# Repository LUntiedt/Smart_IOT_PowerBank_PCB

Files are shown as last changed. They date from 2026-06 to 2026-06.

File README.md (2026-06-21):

# Smart IoT Power Bank — Hardware (PD Edition)

A bidirectional USB-C Power Delivery (PD) power bank built around a software-defined PD stack and an I²C buck-boost charger. This repository holds the **KiCad hardware design** (schematic, layout, BOM, fabrication outputs). The firmware lives in a separate repository.

> **Firmware:** [`smart-iot-power-bank-firmware`](#) 

---

<!-- ───────────────────────────────────────────────────────────── -->
<!-- PROJECT IMAGE — replace the placeholder below with a real photo -->
<!-- Suggested: top-down render or photo of the assembled PCB.       -->
<!-- Drop the file into docs/img/ and update the path.               -->
<!-- ───────────────────────────────────────────────────────────── -->

<p align="center">
  Smart IoT Power Bank PCB
  <br>
  <em>Smart IoT Power Bank</em>
</p>

---

## 1. Overview

The board implements a professional power-management architecture comparable to those found in modern laptops. The same USB-C port handles **input (sink)** and **output (source/OTG)**, limited to a robust **30 W**. Energetic characterization (V/I telemetry, efficiency) is done entirely with the **internal 16-bit ADCs of the charge controller**, avoiding external sense amplifiers.

| Property | Value |
| :--- | :--- |
| Topology | Bidirectional USB-C PD (sink + source) |
| Battery | 4S1P Li-ion, 14.8 V nominal (~45 Wh) with integrated protection BMS |
| Max power | 30 W (5 V / 9 V / 12 V / 15 V / 20 V profiles) |
| MCU | ESP32-C3 (Wi-Fi/BLE) |
| Charger | TI BQ25792 I²C buck-boost |
| PD PHY | onsemi FUSB302B |
| Logic rail | TPS54202 buck → 3.3 V |
| EDA tool | KiCad |
| Fab house | [Aisler](https://aisler.net) (stackup & design rules tuned to Aisler) |

---

## 2. Hardware Architecture

### A. Power Path & USB-C Communication

| Designator | Part | Function | System Role |
| :--- | :--- | :--- | :--- |
| **U3** | `BQ25792RQMR` (TI) | I²C buck-boost charger | Handles charging (buck) and discharging (OTG/boost) in hardware. Single inductor L1 (2.2 µH). |
| **U1** | `FUSB302B11MPX` (onsemi) | USB Type-C PD PHY | Monitors the CC pins and translates PD signalling into I²C messages for the MCU. |
| **U6** | `TPS54202HDDCR` (TI) | 2 A step-down | Generates a clean **3.3 V** logic rail from the fluctuating system voltage. Inductor L2 (10 µH). |
| **Q1, Q2** | `CSD17581Q3A` (TI) | Dual N-channel MOSFETs | Back-to-back FETs for **reverse-polarity protection** / VBUS load isolation; block reverse current from the USB port into the system. |
| **J2** | Würth WR-MPC4 `64900311122` | Battery connector | Connects the external **4S1P 18650 pack** (14.8 V, ~45 Wh, with internal BMS). |

### B. Protection (TVS / ESD / Clamps)

| Designator | Part | Function | Notes |
| :--- | :--- | :--- | :--- |
| **U2, U4** | `TVS2200DRVR` (TI) | Flat-clamp surge protection | **VBUS TVS** — tight clamping on the high-current bus. |
| **D2, D4** | `TPD4E05U06DQAR` (TI) | 4-channel low-cap ESD | Protects **CC lines and the differential pairs** without loading the high-speed signals. |
| **D1** | `ZLLS350` (Diodes Inc.) | 40 V Schottky | Power-path / bootstrap diode. |
| **Z1** | `MMSZ5242B` | 12 V Zener | Rail clamp. |

### C. Sensing & Intelligence (IoT layer)

| Designator | Part | Function | Engineering benefit |
| :--- | :--- | :--- | :--- |
| **U5** | `ESP32-C3-WROOM-02-H4` (Espressif) | Master MCU | FSM control, software PD stack, I²C master, BLE server. |
| — | BQ25792 (internal) | 16-bit ADC telemetry | Reads V_BUS, I_BUS, V_BAT, I_BAT from the charger — no external current sensors. |
| **(TS pin)** | 10 k NTC | Thermistor | Cell temperature monitoring via the BQ25792 TS pin. |
| **J5** | 1×04 header | OLED / I²C | 0.96" OLED for local PD-profile and efficiency readout. |

### D. Connectors, Switches, Indicators

| Designator | Part | Function |
| :--- | :--- | :--- |
| **J1, J3** | USB-C receptacle (Würth `629722000214`) | Two USB-C ports — see differential-pair routing below. |
| **J4** | 2×03 header | Programming / debug header. |
| **SW1, SW2** | Würth tactile `434121025816` | Boot / reset buttons. |
| **D3** | Green LED (Würth) | Status indication. |

> Full part list with manufacturer numbers, footprints and datasheets: **[`ESP_Smart_IoT_Power_Bank.csv`](ESP_Smart_IoT_Power_Bank.csv)**.

---

## 3. Engineering Features & Physics

### I. Cascaded Power Supply (Logic Isolation)

To avoid system reboots under heavy load, the supply is cascaded:

1. **Primary stage** — the BQ25792 generates the system rail `V_SYS` from the 4S pack.
2. **Secondary stage** — a dedicated **TPS54202** bucks `V_SYS` down to a constant **3.3 V** for the logic. The ESP32 therefore always sees a clean rail, independent of current spikes in the power stage.

### II. Efficient 4S Power Routing (Buck & OTG)

The 4S pack (14.8 V) minimizes conversion losses:

* **Buck mode (sink):** at 20 V input the IC acts as an efficient step-down.
* **Buck/boost mode (source):** in OTG, 5 V / 9 V / 12 V are produced highly efficiently by buck conversion; only 20 V profiles (e.g. laptops) require a slight boost.

### III. Thermal & Electrical Derating

Thanks to the 4S configuration, PCB currents stay **below 3 A** even at 30 W:

```
I_bat_max = P_out / (U_bat · η)
I_bat_max = 30 W / (12.0 V · 0.9) ≈ 2.7 A   (worst case, empty pack)
```

On overheat (NTC > 60 °C) the ESP32 throttles PD power via software re-negotiation down to **5 W (5 V / 1 A)** as a fallback.

---

## 4. PCB Stackup & Layout

**4-layer board, built to Aisler's stackup and design rules.**

| Layer | Role |
| :--- | :--- |
| **Top** | Power / Signal |
| **Inner 1** | GND |
| **Inner 2** | GND |
| **Bottom** | Power / Signal |

The dual inner ground planes give the high-speed pairs a continuous reference and a low-impedance return for the power stage.

### Differential pairs

Two **impedance-controlled 90 Ω differential pairs** (USB 2.0 spec):

1. **USB power port (BQ25792):** backwards-compatible USB data for the power path.
2. **Debug/flash port (ESP32-C3):** USB used to flash and debug the MCU.

Both pairs are protected by the low-capacitance `TPD4E05U06` ESD arrays so the added capacitance does not degrade signal integrity.

### Layout guidelines

* **Ground partitioning** — clean ground concept separating the power stage (BQ25792) from the logic (ESP32 / TPS54202).
* **Copper polygons** — power paths (V_BUS, V_BAT, V_SYS) routed as filled polygons.
* **Thermal management** — implemented high power rails on both sides of the board to increase thermal capacity and placing a generous amount of vias to distribute current evenly

---

## 5. Design Decisions Log

* **Dual-MOSFET reverse-polarity protection** (Q1/Q2, CSD17581Q3A) instead of a single series diode — near-zero conduction loss on the power path.
* **VBUS TVS** (TVS2200) for surge clamping on the high-current bus.
* **Low-capacitance TVS/ESD** (TPD4E05U06) on CC lines and the differential pairs to preserve signal integrity.
* **Two 90 Ω impedance-controlled diff pairs:** one for backwards-compatible USB power data (BQ), one dedicated to flashing/debugging the MCU.
* **Aisler** chosen as fab house — the stackup and design rules in this project are tuned to Aisler's process.

---

## 6. Status

Hardware design in KiCad. See the firmware repository for the FreeRTOS PD stack.

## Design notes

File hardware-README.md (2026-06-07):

# Smart IoT Power Bank — Hardware (PD Edition)

A bidirectional USB-C Power Delivery (PD) power bank built around a software-defined PD stack and an I²C buck-boost charger. This repository holds the **KiCad hardware design** (schematic, layout, BOM, fabrication outputs). The firmware lives in a separate repository.

> **Firmware:** [`smart-iot-power-bank-firmware`](#) *(replace with link)*

---

<!-- ───────────────────────────────────────────────────────────── -->
<!-- PROJECT IMAGE — replace the placeholder below with a real photo -->
<!-- Suggested: top-down render or photo of the assembled PCB.       -->
<!-- Drop the file into docs/img/ and update the path.               -->
<!-- ───────────────────────────────────────────────────────────── -->

<p align="center">
  Smart IoT Power Bank PCB
  <br>
  <em>📷 Placeholder — add a photo/render of the power bank here.</em>
</p>

---

## 1. Overview

The board implements a professional power-management architecture comparable to those found in modern laptops. The same USB-C port handles **input (sink)** and **output (source/OTG)**, limited to a robust **30 W**. Energetic characterization (V/I telemetry, efficiency) is done entirely with the **internal 16-bit ADCs of the charge controller**, avoiding external sense amplifiers.

| Property | Value |
| :--- | :--- |
| Topology | Bidirectional USB-C PD (sink + source) |
| Battery | 4S1P Li-ion, 14.8 V nominal (~45 Wh) with integrated protection BMS |
| Max power | 30 W (5 V / 9 V / 12 V / 15 V / 20 V profiles) |
| MCU | ESP32-C3 (Wi-Fi/BLE) |
| Charger | TI BQ25792 I²C buck-boost |
| PD PHY | onsemi FUSB302B |
| Logic rail | TPS54202 buck → 3.3 V |
| EDA tool | KiCad |
| Fab house | [Aisler](https://aisler.net) (stackup & design rules tuned to Aisler) |

---

## 2. Hardware Architecture

### A. Power Path & USB-C Communication

| Designator | Part | Function | System Role |
| :--- | :--- | :--- | :--- |
| **U3** | `BQ25792RQMR` (TI) | I²C buck-boost charger | Handles charging (buck) and discharging (OTG/boost) in hardware. Single inductor L2 (10 µH). |
| **U1** | `FUSB302B11MPX` (onsemi) | USB Type-C PD PHY | Monitors the CC pins and translates PD signalling into I²C messages for the MCU. |
| **U6** | `TPS54202HDDCR` (TI) | 2 A step-down | Generates a clean **3.3 V** logic rail from the fluctuating system voltage. Inductor L1 (2.2 µH). |
| **Q1, Q2** | `CSD17581Q3A` (TI) | Dual N-channel MOSFETs | Back-to-back FETs for **reverse-polarity protection** / VBUS load isolation; block reverse current from the USB port into the system. |
| **J2** | Würth WR-MPC4 `64900311122` | Battery connector | Connects the external **4S1P 18650 pack** (14.8 V, ~45 Wh, with internal BMS). |

### B. Protection (TVS / ESD / Clamps)

| Designator | Part | Function | Notes |
| :--- | :--- | :--- | :--- |
| **U2, U4** | `TVS2200DRVR` (TI) | Flat-clamp surge protection | **VBUS TVS** — tight clamping on the high-current bus. |
| **D2, D4** | `TPD4E05U06DQAR` (TI) | 4-channel low-cap ESD | Protects **CC lines and the differential pairs** without loading the high-speed signals. |
| **D1** | `ZLLS350` (Diodes Inc.) | 40 V Schottky | Power-path / bootstrap diode. |
| **Z1** | `MMSZ5242B` | 12 V Zener | Rail clamp. |

### C. Sensing & Intelligence (IoT layer)

| Designator | Part | Function | Engineering benefit |
| :--- | :--- | :--- | :--- |
| **U5** | `ESP32-C3-WROOM-02-H4` (Espressif) | Master MCU | FSM control, software PD stack, I²C master, BLE server. |
| — | BQ25792 (internal) | 16-bit ADC telemetry | Reads V_BUS, I_BUS, V_BAT, I_BAT from the charger — no external current sensors. |
| **(TS pin)** | 10 k NTC | Thermistor | Cell temperature monitoring via the BQ25792 TS pin. |
| **J5** | 1×04 header | OLED / I²C | 0.96" OLED for local PD-profile and efficiency readout. |

### D. Connectors, Switches, Indicators

| Designator | Part | Function |
| :--- | :--- | :--- |
| **J1, J3** | USB-C receptacle (Würth `629722000214`) | Two USB-C ports — see differential-pair routing below. |
| **J4** | 2×03 header | Programming / debug header. |
| **SW1, SW2** | Würth tactile `434121025816` | Boot / reset buttons. |
| **D3** | Green LED (Würth) | Status indication. |

> Full part list with manufacturer numbers, footprints and datasheets: **[`ESP_Smart_IoT_Power_Bank.csv`](ESP_Smart_IoT_Power_Bank.csv)**.

---

## 3. Engineering Features & Physics

### I. Cascaded Power Supply (Logic Isolation)

To avoid system reboots under heavy load, the supply is cascaded:

1. **Primary stage** — the BQ25792 generates the system rail `V_SYS` from the 4S pack.
2. **Secondary stage** — a dedicated **TPS54202** bucks `V_SYS` down to a constant **3.3 V** for the logic. The ESP32 therefore always sees a clean rail, independent of current spikes in the power stage.

### II. Efficient 4S Power Routing (Buck & OTG)

The 4S pack (14.8 V) minimizes conversion losses:

* **Buck mode (sink):** at 20 V input the IC acts as an efficient step-down.
* **Buck/boost mode (source):** in OTG, 5 V / 9 V / 12 V are produced highly efficiently by buck conversion; only 20 V profiles (e.g. laptops) require a slight boost.

### III. Thermal & Electrical Derating

Thanks to the 4S configuration, PCB currents stay **below 3 A** even at 30 W:

```
I_bat_max = P_out / (U_bat · η)
I_bat_max = 30 W / (12.0 V · 0.9) ≈ 2.7 A   (worst case, empty pack)
```

On overheat (NTC > 60 °C) the ESP32 throttles PD power via software re-negotiation down to **5 W (5 V / 1 A)** as a fallback.

---

## 4. PCB Stackup & Layout

**4-layer board, built to Aisler's stackup and design rules.**

| Layer | Role |
| :--- | :--- |
| **Top** | Signal |
| **Inner 1** | GND |
| **Inner 2** | GND |
| **Bottom** | Power / Signal |

The dual inner ground planes give the high-speed pairs a continuous reference and a low-impedance return for the power stage.

### Differential pairs

Two **impedance-controlled 90 Ω differential pairs** (USB 2.0 spec):

1. **USB power port (BQ25792):** backwards-compatible USB data for the power path.
2. **Debug/flash port (ESP32-C3):** USB used to flash and debug the MCU.

Both pairs are protected by the low-capacitance `TPD4E05U06` ESD arrays so the added capacitance does not degrade signal integrity.

### Layout guidelines

* **Ground partitioning** — clean ground concept separating the power stage (BQ25792) from the logic (ESP32 / TPS54202).
* **Copper polygons** — power paths (V_BUS, V_BAT, V_SYS) routed as filled polygons.
* **Thermal management** — the BQ25792 thermal pad uses a dense GND-via array to conduct heat into the inner copper layers.

---

## 5. Design Decisions Log

* **Dual-MOSFET reverse-polarity protection** (Q1/Q2, CSD17581Q3A) instead of a single series diode — near-zero conduction loss on the power path.
* **VBUS TVS** (TVS2200) for surge clamping on the high-current bus.
* **Low-capacitance TVS/ESD** (TPD4E05U06) on CC lines and the differential pairs to preserve signal integrity.
* **Two 90 Ω impedance-controlled diff pairs:** one for backwards-compatible USB power data (BQ), one dedicated to flashing/debugging the MCU.
* **Aisler** chosen as fab house — the stackup and design rules in this project are tuned to Aisler's process.

---

## 6. Repository Structure

```
.
├── docs/
│   └── img/                 # photos / renders (add powerbank.png here)
├── *.kicad_pro              # KiCad project
├── *.kicad_sch              # schematic
├── *.kicad_pcb              # board layout
├── ESP_Smart_IoT_Power_Bank.csv   # bill of materials
└── README.md
```

## 7. Status

Hardware design in KiCad. See the firmware repository for the FreeRTOS PD stack.

## 8. License

*Add a license (e.g. CERN-OHL-S for hardware) before publishing.*

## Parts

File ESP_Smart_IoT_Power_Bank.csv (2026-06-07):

Reference | Qty | Value | DNP | Exclude from BOM | Exclude from Board | Footprint | Datasheet | Manufacturer_Part_Number
C1,C35 | 2 | 1n |  |  |  | 00_PowerBank_FTP:C_Wurth_WCAP-CSGP-0402 | https://www.we-online.com/catalog/datasheet/885012205061.pdf?ki | 885012205061
C2,C3,C6,C38,C40 | 5 | 1u |  |  |  | 00_PowerBank_FTP:C_Wurth_WCAP-CSGP-1206_H1.6 | https://www.we-online.com/catalog/datasheet/885012208093.pdf?ki | 885012208093
C4 | 1 | 10n |  |  |  | 00_PowerBank_FTP:C_Wurth_WCAP-CSGP-0402 | https://www.we-online.com/catalog/datasheet/885012205067.pdf?ki | 885012205067
C5,C7,C17,C18,C20,C30,C33,C37,C41,C44 | 10 | 100n |  |  |  | 00_PowerBank_FTP:C_Wurth_WCAP-CSGP-0402 | https://www.we-online.com/catalog/datasheet/885012205086.pdf?ki | 885012205086
C8,C13,C14,C15,C16,C21,C22,C23,C24,C25,C27,C28,C29,C31,C32,C36,C42,C43 | 18 | 10u |  |  |  | 00_PowerBank_FTP:C_Wurth_WCAP-CSGP-1206_H1.6 | https://www.we-online.com/catalog/datasheet/885012208069.pdf?ki | 885012208069
C9,C10 | 2 | 330p |  |  |  | 00_PowerBank_FTP:C_Wurth_WCAP-CSGP-0402 | https://www.we-online.com/catalog/datasheet/885012005016.pdf?ki | 885012005016
C11,C39 | 2 | 4n7 |  |  |  | 00_PowerBank_FTP:C_Wurth_WCAP-CSGP-0402 | https://www.we-online.com/catalog/datasheet/885012205065.pdf?ki | 885012205065
C12,C19 | 2 | 47n |  |  |  | 00_PowerBank_FTP:C_Wurth_WCAP-CSGP-0402 | https://www.we-online.com/catalog/datasheet/885012205054.pdf?ki | 885012205054
C26 | 1 | 4u7 |  |  |  | 00_PowerBank_FTP:C_Wurth_WCAP-CSGP-1206_H1.6 | https://www.we-online.com/catalog/datasheet/885012208068.pdf?ki | 885012208068
C34 | 1 | 47n |  |  |  | 00_PowerBank_FTP:C_Wurth_WCAP-CSGP-0603_R | https://www.we-online.com/catalog/datasheet/885012206093.pdf?ki | 885012206093
C45,C46 | 2 | 22u |  |  |  | 00_PowerBank_FTP:C_Wurth_WCAP-CSGP-1206_H1.6 | https://www.we-online.com/catalog/datasheet/885012108018.pdf?ki | 885012108018
C47 | 1 | 56p |  |  |  | 00_PowerBank_FTP:C_Wurth_WCAP-CSGP-0402 | http://www.vishay.com/docs/45226/vj31xrohsautomlcc.pdf | VJ0402A560JXAAC
D1 | 1 | 40V |  |  |  | 00_PowerBank_FTP:SODFL1608X65N | https://www.diodes.com//assets/Datasheets/ZLLS350.pdf | ZLLS350TA
D2,D4 | 2 | TPD4E05U06DQAR |  |  |  | 00_PowerBank_FTP:DQA_R-PUSON-N10_ | http://www.ti.com/lit/gpn/tpd4e05u06 | TPD4E05U06DQAR
D3 | 1 | Green |  |  |  | 00_PowerBank_FTP:D_Wurth_WL-SMCW-0603 | https://www.we-online.com/catalog/datasheet/150060VS75000.pdf?ki | 150060VS75000
J1,J3 | 2 | USB_C_Receptacle_USB2.0_16P_Wuerth_Lorenzo |  |  |  | 00_PowerBank_FTP:629722000214 | https://www.usb.org/sites/default/files/documents/usb_type-c.zip | 629722000214
J2 | 1 | 64900311122 |  |  |  | 00_PowerBank_FTP:J_Wurth_WR-MPC4_64900311122 | https://www.we-online.com/en/components/products/datasheet/64900311122?ki | 64900311122
J4 | 1 | Conn_02x03_Odd_Even |  |  |  | Connector_PinHeader_2.54mm:PinHeader_2x03_P2.54mm_Vertical
J5 | 1 | Conn_01x04_Pin |  |  |  | Connector_PinHeader_2.54mm:PinHeader_1x04_P2.54mm_Vertical
L1 | 1 | 2.2 uH |  |  |  | 00_PowerBank_FTP:L_Wurth_WE-LHMI-7030 | https://www.we-online.com/catalog/datasheet/74437346022.pdf?ki | 74437346022
L2 | 1 | 10.0 uH |  |  |  | 00_PowerBank_FTP:L_Wurth_WE-LHMI-7050 | https://www.we-online.com/catalog/datasheet/74437349100.pdf?ki | 74437349100
Q1,Q2 | 2 | CSD17581Q3A |  |  |  | 00_PowerBank_FTP:CSD17581Q3A_LorenzonF | https://www.ti.com/lit/ds/symlink/csd17581q3a.pdf | CSD17581Q3A
R1 | 1 | 2 |  |  |  | 00_PowerBank_FTP:R_Wurth_WRIS-RSKS-0402 | https://www.we-online.com/catalog/datasheet/560112110057.pdf?ki | 560112110057
R2 | 1 | 301 |  |  |  | 00_PowerBank_FTP:R_Wurth_WRIS-RSKS-0402 | https://www.we-online.com/catalog/datasheet/560112110092.pdf?ki | 560112110092
R3,R16 | 2 | 1M |  |  |  | 00_PowerBank_FTP:R_Wurth_WRIS-RSKS-0402 | https://www.we-online.com/catalog/datasheet/560112110033.pdf?ki | 560112110033
R4 | 1 | 2k2 |  |  |  | 00_PowerBank_FTP:R_Wurth_WRIS-RSKS-0402 | https://www.we-online.com/catalog/datasheet/560112110087.pdf?ki | 560112110087
R5 | 1 | 100 |  |  |  | 00_PowerBank_FTP:R_Wurth_WRIS-RSKS-0402 | https://www.we-online.com/catalog/datasheet/560112110022.pdf?ki | 560112110022
R6 | 1 | 127k |  |  |  | 00_PowerBank_FTP:R_Wurth_WRIS-RSKS-0402 | https://www.we-online.com/catalog/datasheet/560112110195.pdf?ki | 560112110195
R7 | 1 | 27k |  |  |  | 00_PowerBank_FTP:R_Wurth_WRIS-RSKS-0402 | https://www.we-online.com/catalog/datasheet/560112110026.pdf?ki | 560112110026
R8,R26 | 2 | 100k |  |  |  | 00_PowerBank_FTP:R_Wurth_WRIS-RSKS-0402 | https://www.we-online.com/catalog/datasheet/560112110019.pdf?ki | 560112110019
R9 | 1 | 5k23 |  |  |  | 00_PowerBank_FTP:R_Wurth_WRIS-RSKS-0402 | https://industrial.panasonic.com/cdbs/www-data/pdf/RDP0000/AOA0000C334.pdf | ERJ-U02D5231X
R10 | 1 | 30k1 |  |  |  | 00_PowerBank_FTP:R_Wurth_WRIS-RSKS-0402 |  | ERJ-2RHD3012X
R11,R12 | 2 | 4k7 |  |  |  | 00_PowerBank_FTP:R_Wurth_WRIS-RSKS-0402 | https://www.we-online.com/catalog/datasheet/560112110245.pdf?ki | 560112110245
R13,R18 | 2 | 1k |  |  |  | 00_PowerBank_FTP:R_Wurth_WRIS-RSKS-0402 | https://www.we-online.com/catalog/datasheet/560112110012.pdf?ki | 560112110012
R14,R15,R17,R19,R23,R25 | 6 | 10k |  |  |  | 00_PowerBank_FTP:R_Wurth_WRIS-RSKS-0402 | https://www.we-online.com/catalog/datasheet/560112110020.pdf?ki | 560112110020
R20,R21 | 2 | 5k1 |  |  |  | 00_PowerBank_FTP:R_Wurth_WRIS-RSKS-0402 | http://docs-europe.electrocomponents.com/webdocs/13ba/0900766b813ba21b.pdf | ERJ2RKF5101X
R22 | 1 | 510k |  |  |  | 00_PowerBank_FTP:R_Wurth_WRIS-RSKS-0402 | https://industrial.panasonic.com/cdbs/www-data/pdf/RDP0000/AOA0000C334.pdf | ERJ-U02F5103X
R24 | 1 | 49.9 |  |  |  | 00_PowerBank_FTP:R_Wurth_WRIS-RSKS-0402 | https://www.we-online.com/catalog/datasheet/560112110002.pdf?ki | 560112110002
R27 | 1 | 22k1 |  |  |  | 00_PowerBank_FTP:R_Wurth_WRIS-RSKS-0402 | https://www.we-online.com/catalog/datasheet/560112110099.pdf?ki | 560112110099
SW1,SW2 | 2 | 434121025816 |  |  |  | 00_PowerBank_FTP:SW_Wurth_WS-TASV_434121025816 | https://www.we-online.com/catalog/datasheet/434121025816.pdf?ki | 434121025816
U1 | 1 | FUSB302B11MPX |  |  |  | 00_PowerBank_FTP:QFN50P250X250X80-15N | https://www.onsemi.com/pub/Collateral/FUSB302B-D.PDF | FUSB302B11MPX
U2,U4 | 2 | TVS2200DRVR |  |  |  | 00_PowerBank_FTP:SON65P200X200X80-7N | https://www.ti.com/lit/ds/symlink/tvs2200.pdf?ts=1636348695619 | TVS2200DRVR
U3 | 1 | BQ25792RQMR |  |  |  | 00_PowerBank_FTP:BQ25792RQMR |  | BQ25792RQMR
U5 | 1 | ESP32-C3-WROOM-02-H4 |  |  |  | 00_PowerBank_FTP:ESP32C3WROOM02H4 | https://www.mouser.in/datasheet/2/891/Espressif_Systems_04082021_ESP32_C3_WROOM_02-2295851.pdf | ESP32-C3-WROOM-02-H4
U6 | 1 | TPS54202HDDCR |  |  |  | 00_PowerBank_FTP:SOT95P280X110-6N | http://www.ti.com/lit/gpn/tps54202h | TPS54202HDDCR
Z1 | 1 | 12V |  |  |  | 00_PowerBank_FTP:SOD3716X145N | https://www.diodes.com//assets/Datasheets/ds18010.pdf | MMSZ5242B-7-F

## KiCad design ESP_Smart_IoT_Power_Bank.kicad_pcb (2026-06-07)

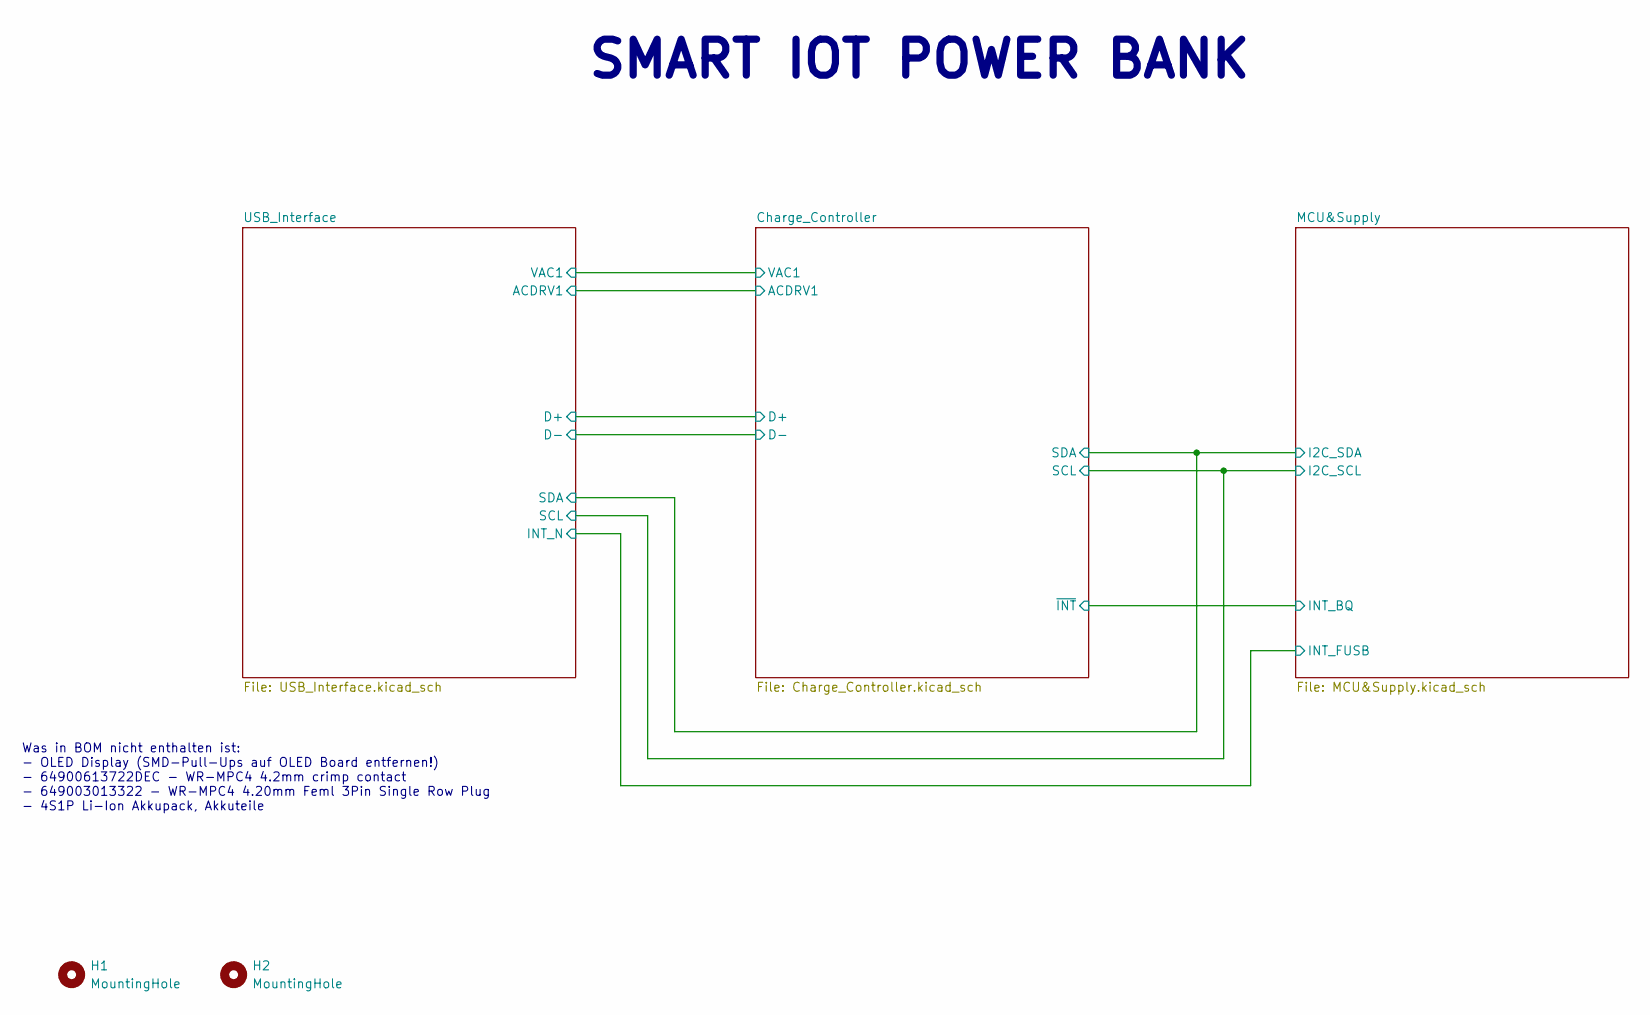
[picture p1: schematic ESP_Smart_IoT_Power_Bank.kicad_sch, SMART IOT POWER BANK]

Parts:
H1, H2: MountingHole; MountingHole_3.2mm_M3_ISO14580

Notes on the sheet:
SMART IOT POWER BANK
Was in BOM nicht enthalten ist: - OLED Display (SMD-Pull-Ups auf OLED Board entfernen!) - 64900613722DEC - WR-MPC4 4.2mm crimp contact - 649003013322 - WR-MPC4 4.20mm Feml 3Pin Single Row Plug - 4S1P Li-Ion Akkupack, Akkuteile

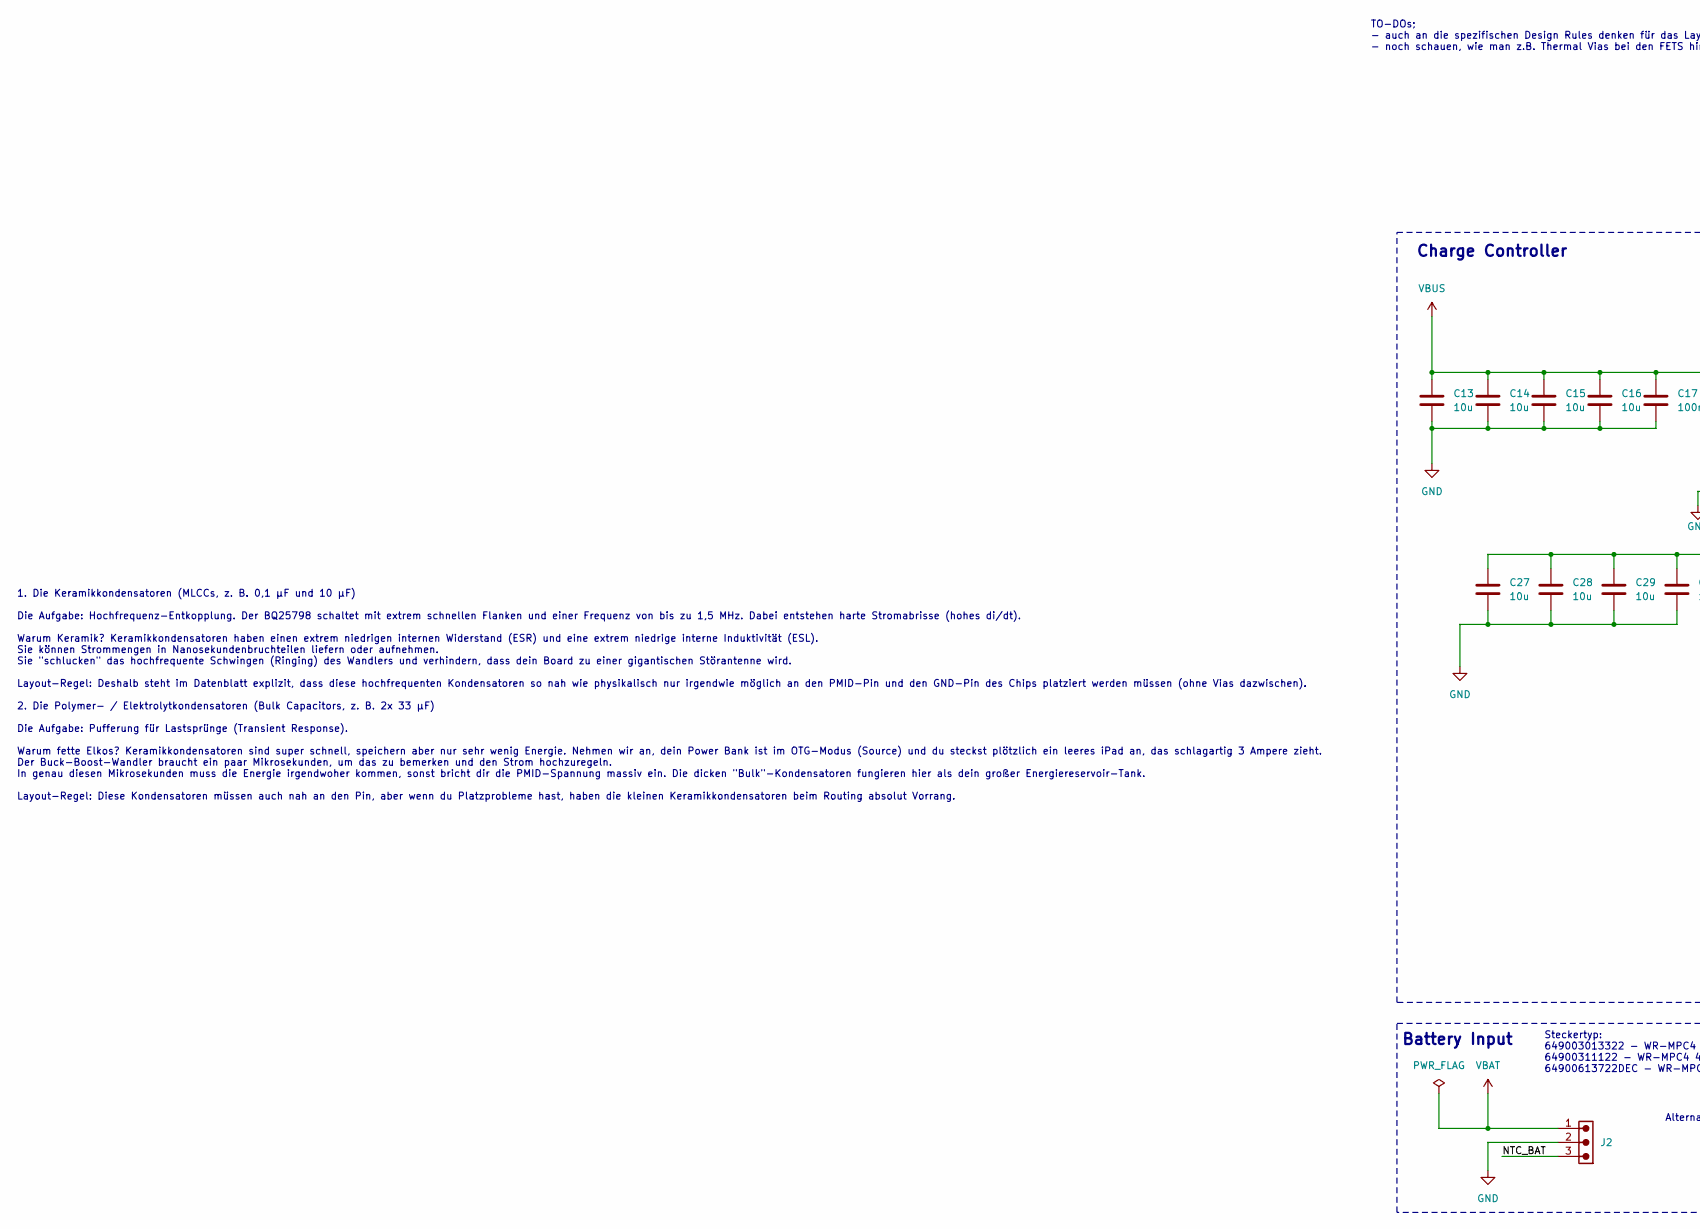
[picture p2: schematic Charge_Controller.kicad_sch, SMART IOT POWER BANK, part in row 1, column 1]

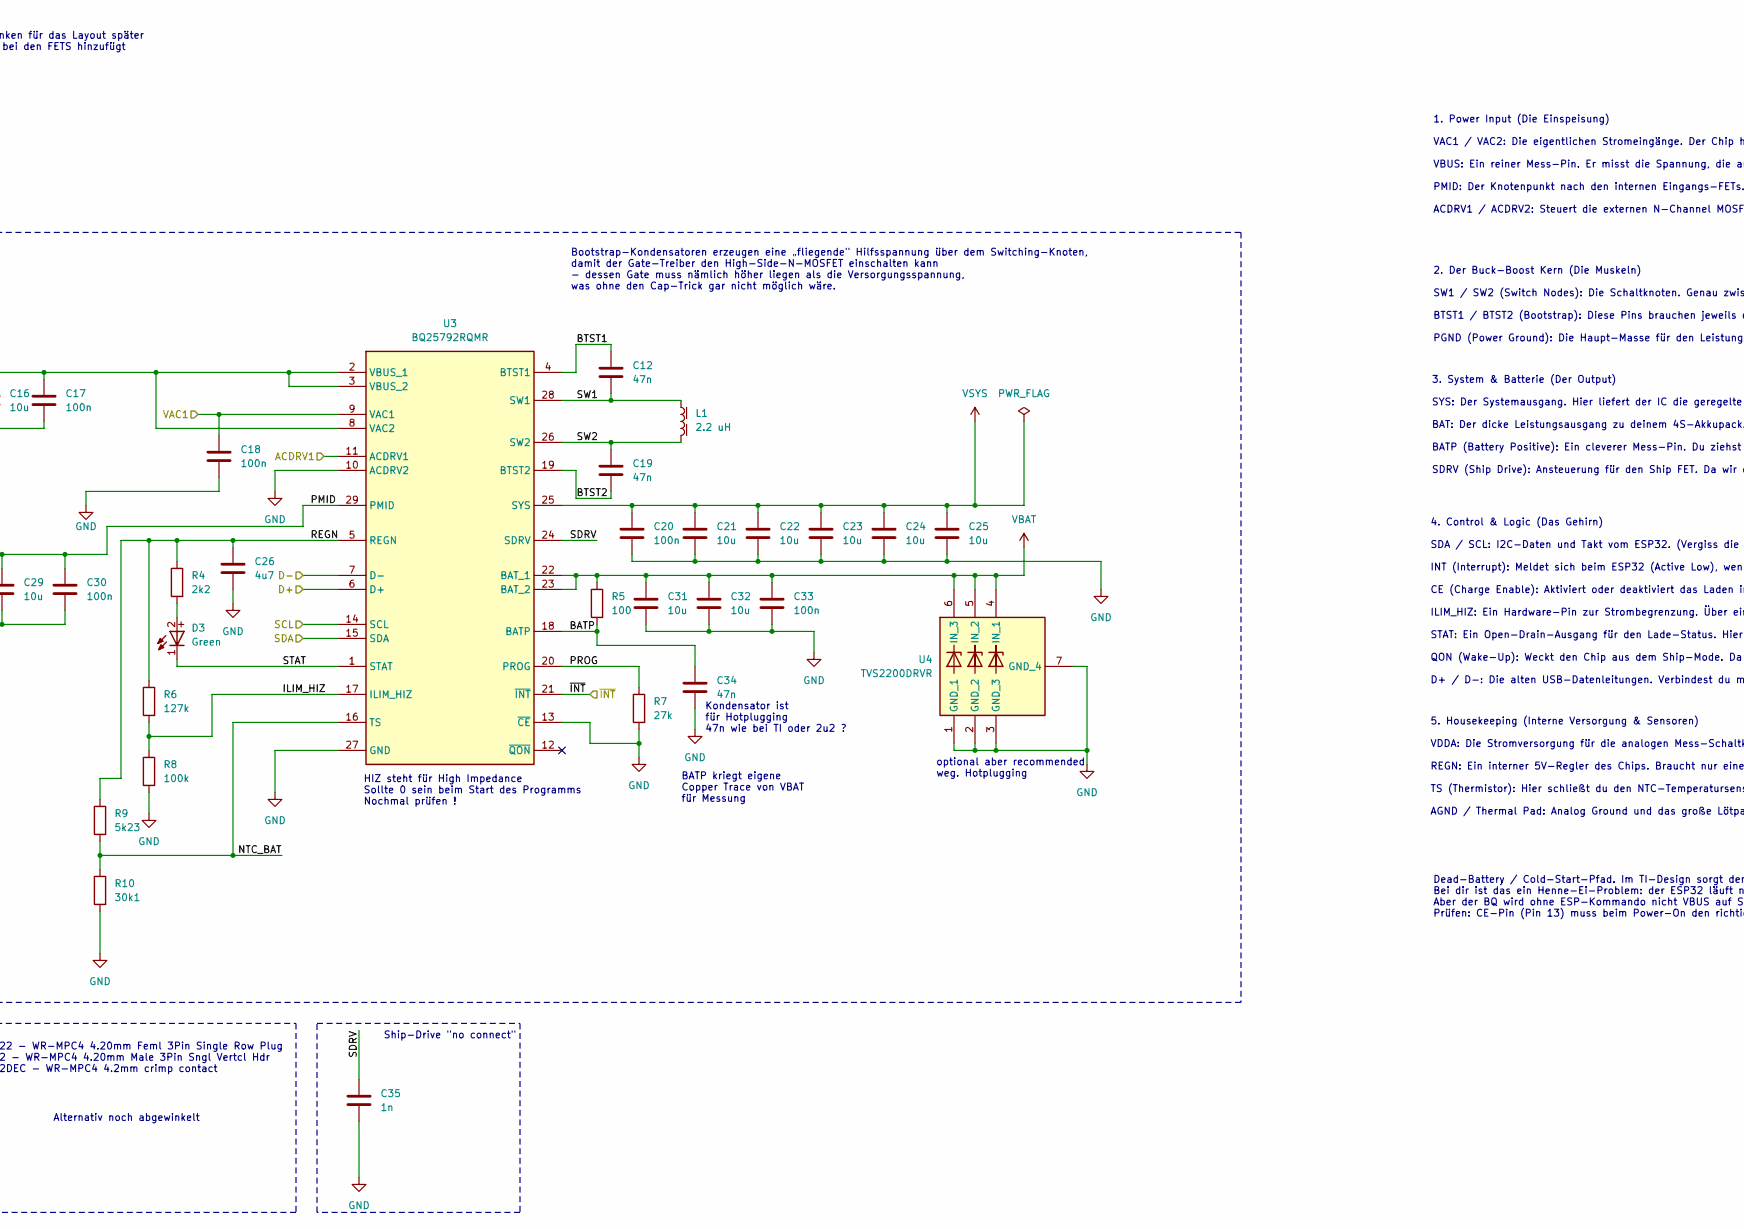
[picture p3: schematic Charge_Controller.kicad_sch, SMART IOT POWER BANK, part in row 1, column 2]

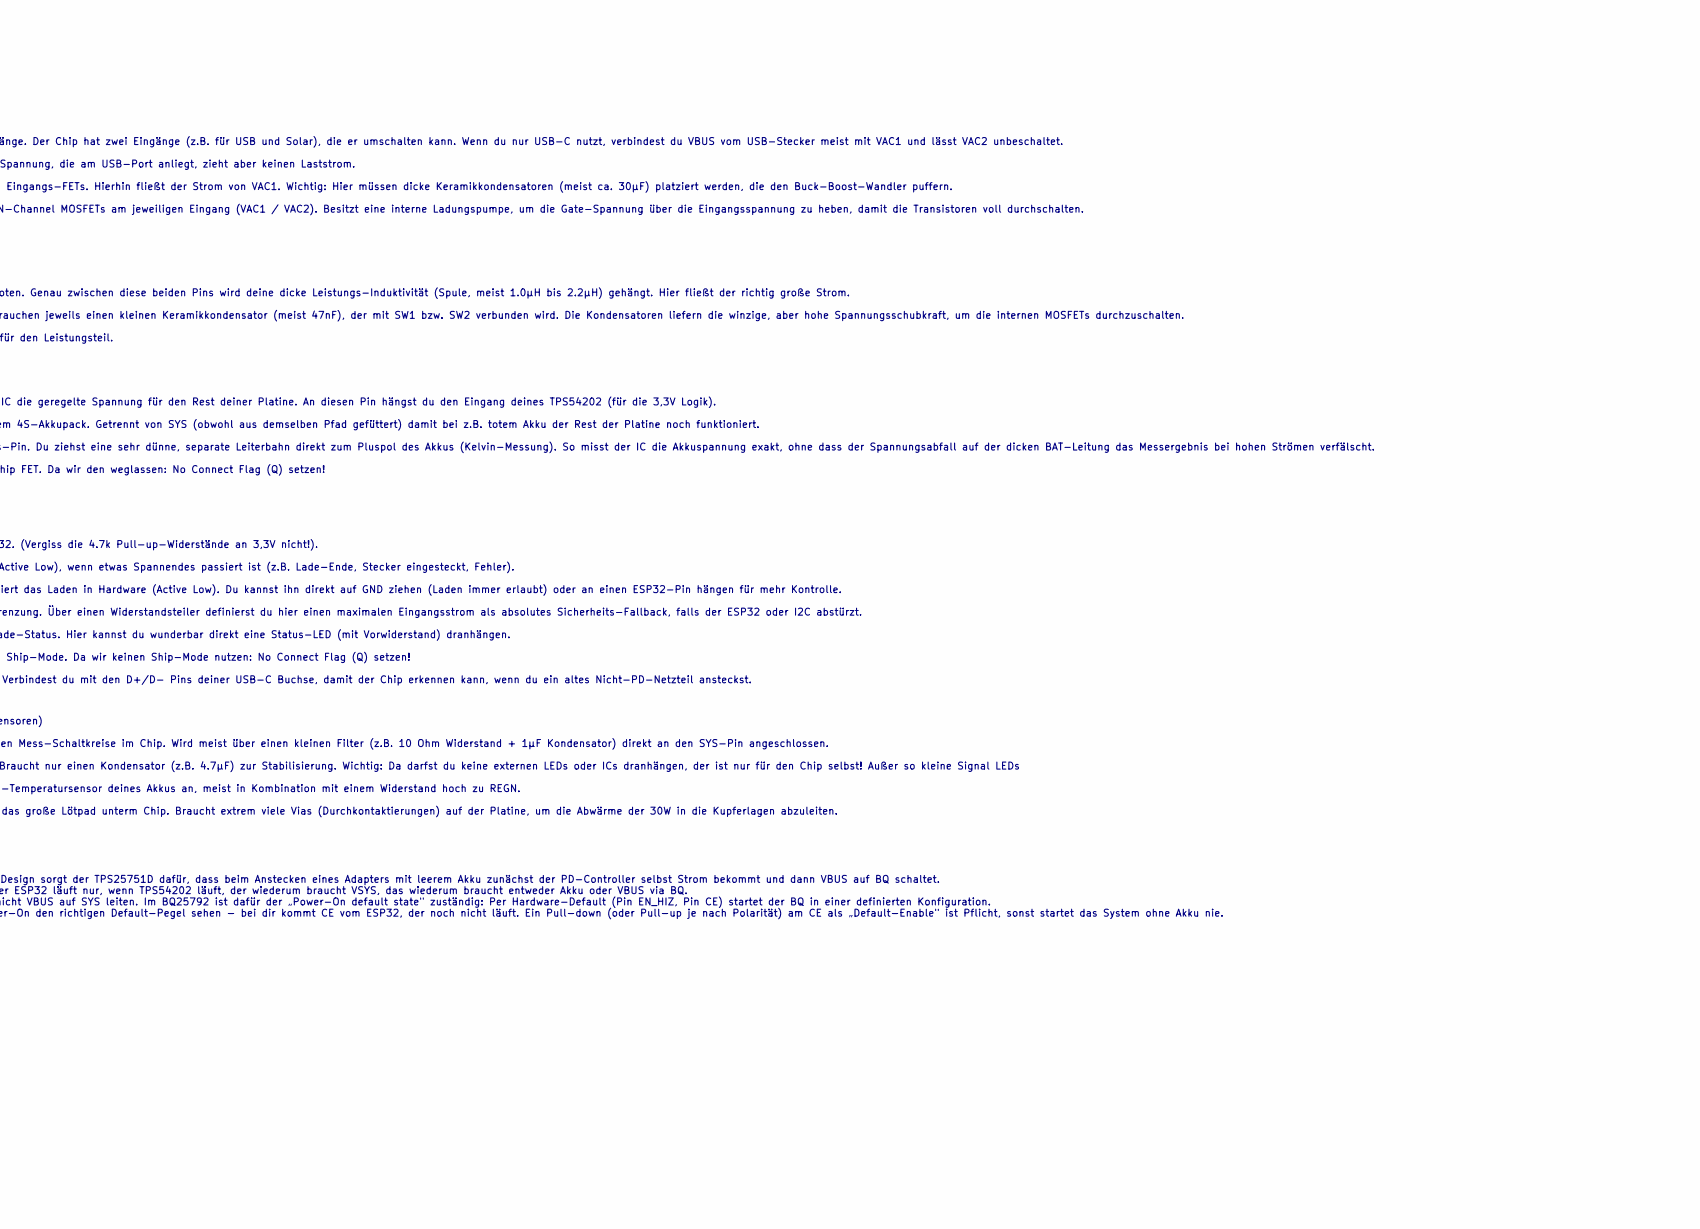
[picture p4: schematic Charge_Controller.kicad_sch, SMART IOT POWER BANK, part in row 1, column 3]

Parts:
C12, C19: 47n; C_Wurth_WCAP-CSGP-0402; Voltage 25.0; Manufacturer_Part_Number 885012205054
C13, C14, C15, C16, C21, C22, C23, C24, C25, C27, C28, C29, C31, C32: 10u; C_Wurth_WCAP-CSGP-1206_H1.6; Voltage 25.0; Part Number 885012208069
C17, C18, C20, C30, C33: 100n; C_Wurth_WCAP-CSGP-0402; Voltage 50.0; Part Number 885012205086
C26: 4u7; C_Wurth_WCAP-CSGP-1206_H1.6; Voltage 25.0; Part Number 885012208068
C34: 47n; C_Wurth_WCAP-CSGP-0603_R; Voltage 50.0; Part Number 885012206093
C35: 1n; C_Wurth_WCAP-CSGP-0402; Voltage 50.0; Part Number 885012205061
D3: Green; D_Wurth_WL-SMCW-0603; Part Number 150060VS75000
J2: 64900311122; J_Wurth_WR-MPC4_64900311122; Working Voltage (V (AC)) 600; Manufacturer_Part_Number 64900311122
L1: 2.2 uH; L_Wurth_WE-LHMI-7030; Part Number 74437346022
R4: 2k2; R_Wurth_WRIS-RSKS-0402; Part Number 560112110087
R5: 100; R_Wurth_WRIS-RSKS-0402; Part Number 560112110022
R6: 127k; R_Wurth_WRIS-RSKS-0402; Part Number 560112110195
R7: 27k; R_Wurth_WRIS-RSKS-0402; Part Number 560112110026
R8: 100k; R_Wurth_WRIS-RSKS-0402; Part Number 560112110019
R9: 5k23; R_Wurth_WRIS-RSKS-0402; Manufacturer_Part_Number ERJ-U02D5231X
R10: 30k1; R_Wurth_WRIS-RSKS-0402; Mouser Part Number 667-ERJ-2RHD3012X
U3: BQ25792RQMR; Mouser Part Number 595-BQ25792RQMR
U4: TVS2200DRVR; SON65P200X200X80-7N; Mouser Part Number 595-TVS2200DRVR

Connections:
/Charge_Controller/ACDRV1: U3.11 (ACDRV1); also elsewhere on the board
/Charge_Controller/BATP: C34.1, R5.1, U3.18 (BATP)
/Charge_Controller/BTST1: C12.1, U3.4 (BTST1)
/Charge_Controller/BTST2: C19.2, U3.19 (BTST2)
/Charge_Controller/D+: U3.6 (D+); also elsewhere on the board
/Charge_Controller/D-: U3.7 (D-); also elsewhere on the board
/Charge_Controller/ILIM_HIZ: R6.1, R8.2, U3.17 (ILIM_HIZ)
/Charge_Controller/NTC_BAT: J2.3, R9.1, R10.2, U3.16 (TS)
/Charge_Controller/PMID: C27.1, C28.1, C29.1, C30.1, U3.29 (PMID)
/Charge_Controller/PROG: R7.2, U3.20 (PROG)
/Charge_Controller/REGN: C26.1, R4.2, R6.2, R9.2, U3.5 (REGN)
/Charge_Controller/SDRV: C35.1, U3.24 (SDRV)
/Charge_Controller/STAT: D3.1 (-), U3.1 (STAT)
/Charge_Controller/SW1: C12.2, L1.1, U3.28 (SW1)
/Charge_Controller/SW2: C19.1, L1.2, U3.26 (SW2)
/Charge_Controller/~INT: U3.21 (~INT); also elsewhere on the board
/MCU&Supply/I2C_SCL: U3.14 (SCL); also elsewhere on the board
/MCU&Supply/I2C_SDA: U3.15 (SDA); also elsewhere on the board
/USB_Interface/VBUS_RAW: C18.1, U3.9 (VAC1); also elsewhere on the board
GND: C13.2, C14.2, C15.2, C16.2, C17.2, C18.2, C20.2, C21.2, C22.2, C23.2, C24.2, C25.2, C26.2, C27.2, C28.2, C29.2, C30.2, C31.2, C32.2, C33.2, C34.2, C35.2, J2.2, R7.1, R8.1, R10.1, U3.10 (ACDRV2), U3.13 (~CE), U3.27 (GND), U4.1 (GND_1), U4.2 (GND_2), U4.3 (GND_3), U4.7 (GND_4); also elsewhere on the board
unnamed: D3.2 (+), R4.1
VBAT: C31.1, C32.1, C33.1, J2.1, R5.2, U3.22 (BAT_1), U3.23 (BAT_2), U4.4 (IN_1), U4.5 (IN_2), U4.6 (IN_3)
VBUS: C13.1, C14.1, C15.1, C16.1, C17.1, U3.2 (VBUS_1), U3.3 (VBUS_2), U3.8 (VAC2); also elsewhere on the board
VSYS: C20.1, C21.1, C22.1, C23.1, C24.1, C25.1, U3.25 (SYS); also elsewhere on the board

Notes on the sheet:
3. System & Batterie (Der Output) SYS: Der Systemausgang. Hier liefert der IC die geregelte Spannung für den Rest deiner Platine. An diesen Pin hängst du den Eingang deines TPS54202 (für die 3,3V Logik). BAT: Der dicke Leistungsausgang zu deinem 4S-Akkupack. Getrennt von SYS (obwohl aus demselben P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
1. Die Keramikkondensatoren (MLCCs, z. B. 0,1 µF und 10 µF) Die Aufgabe: Hochfrequenz-Entkopplung. Der BQ25798 schaltet mit extrem schnellen Flanken und einer Frequenz von bis zu 1,5 MHz. Dabei entstehen harte Stromabrisse (hohes di/dt). Warum Keramik? Keramikkondensatoren haben einen extrem niedri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
1. Power Input (Die Einspeisung) VAC1 / VAC2: Die eigentlichen Stromeingänge. Der Chip hat zwei Eingänge (z.B. für USB und Solar), die er umschalten kann. Wenn du nur USB-C nutzt, verbindest du VBUS vom USB-Stecker meist mit VAC1 und lässt VAC2 unbeschaltet. VBUS: Ein reiner Mess-Pin. Er misst die 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
2. Der Buck-Boost Kern (Die Muskeln) SW1 / SW2 (Switch Nodes): Die Schaltknoten. Genau zwischen diese beiden Pins wird deine dicke Leistungs-Induktivität (Spule, meist 1.0µH bis 2.2µH) gehängt. Hier fließt der richtig große Strom. BTST1 / BTST2 (Bootstrap): Diese Pins brauchen jeweils einen kleinen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
Bootstrap-Kondensatoren erzeugen eine „fliegende" Hilfsspannung über dem Switching-Knoten, damit der Gate-Treiber den High-Side-N-MOSFET einschalten kann - dessen Gate muss nämlich höher liegen als die Versorgungsspannung, was ohne den Cap-Trick gar nicht möglich wäre.
Charge Controller
Battery Input
HIZ steht für High Impedance Sollte 0 sein beim Start des Programms Nochmal prüfen !
Kondensator ist für Hotplugging 47n wie bei TI oder 2u2 ?
Ship-Drive "no connect"
Steckertyp: 649003013322 - WR-MPC4 4.20mm Feml 3Pin Single Row Plug 64900311122 - WR-MPC4 4.20mm Male 3Pin Sngl Vertcl Hdr 64900613722DEC - WR-MPC4 4.2mm crimp contact
BATP kriegt eigene Copper Trace von VBAT für Messung
TO-DOs; - auch an die spezifischen Design Rules denken für das Layout später - noch schauen, wie man z.B. Thermal Vias bei den FETS hinzufügt
optional aber recommended weg. Hotplugging
4. Control & Logic (Das Gehirn) SDA / SCL: I2C-Daten und Takt vom ESP32. (Vergiss die 4.7k Pull-up-Widerstände an 3,3V nicht!). INT (Interrupt): Meldet sich beim ESP32 (Active Low), wenn etwas Spannendes passiert ist (z.B. Lade-Ende, Stecker eingesteckt, Fehler). CE (Charge Enable): Aktiviert oder 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
5. Housekeeping (Interne Versorgung & Sensoren) VDDA: Die Stromversorgung für die analogen Mess-Schaltkreise im Chip. Wird meist über einen kleinen Filter (z.B. 10 Ohm Widerstand + 1µF Kondensator) direkt an den SYS-Pin angeschlossen. REGN: Ein interner 5V-Regler des Chips. Braucht nur einen Konden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
Dead-Battery / Cold-Start-Pfad. Im TI-Design sorgt der TPS25751D dafür, dass beim Anstecken eines Adapters mit leerem Akku zunächst der PD-Controller selbst Strom bekommt und dann VBUS auf BQ schaltet. Bei dir ist das ein Henne-Ei-Problem: der ESP32 läuft nur, wenn TPS54202 läuft, der wiederum brau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
Alternativ noch abgewinkelt

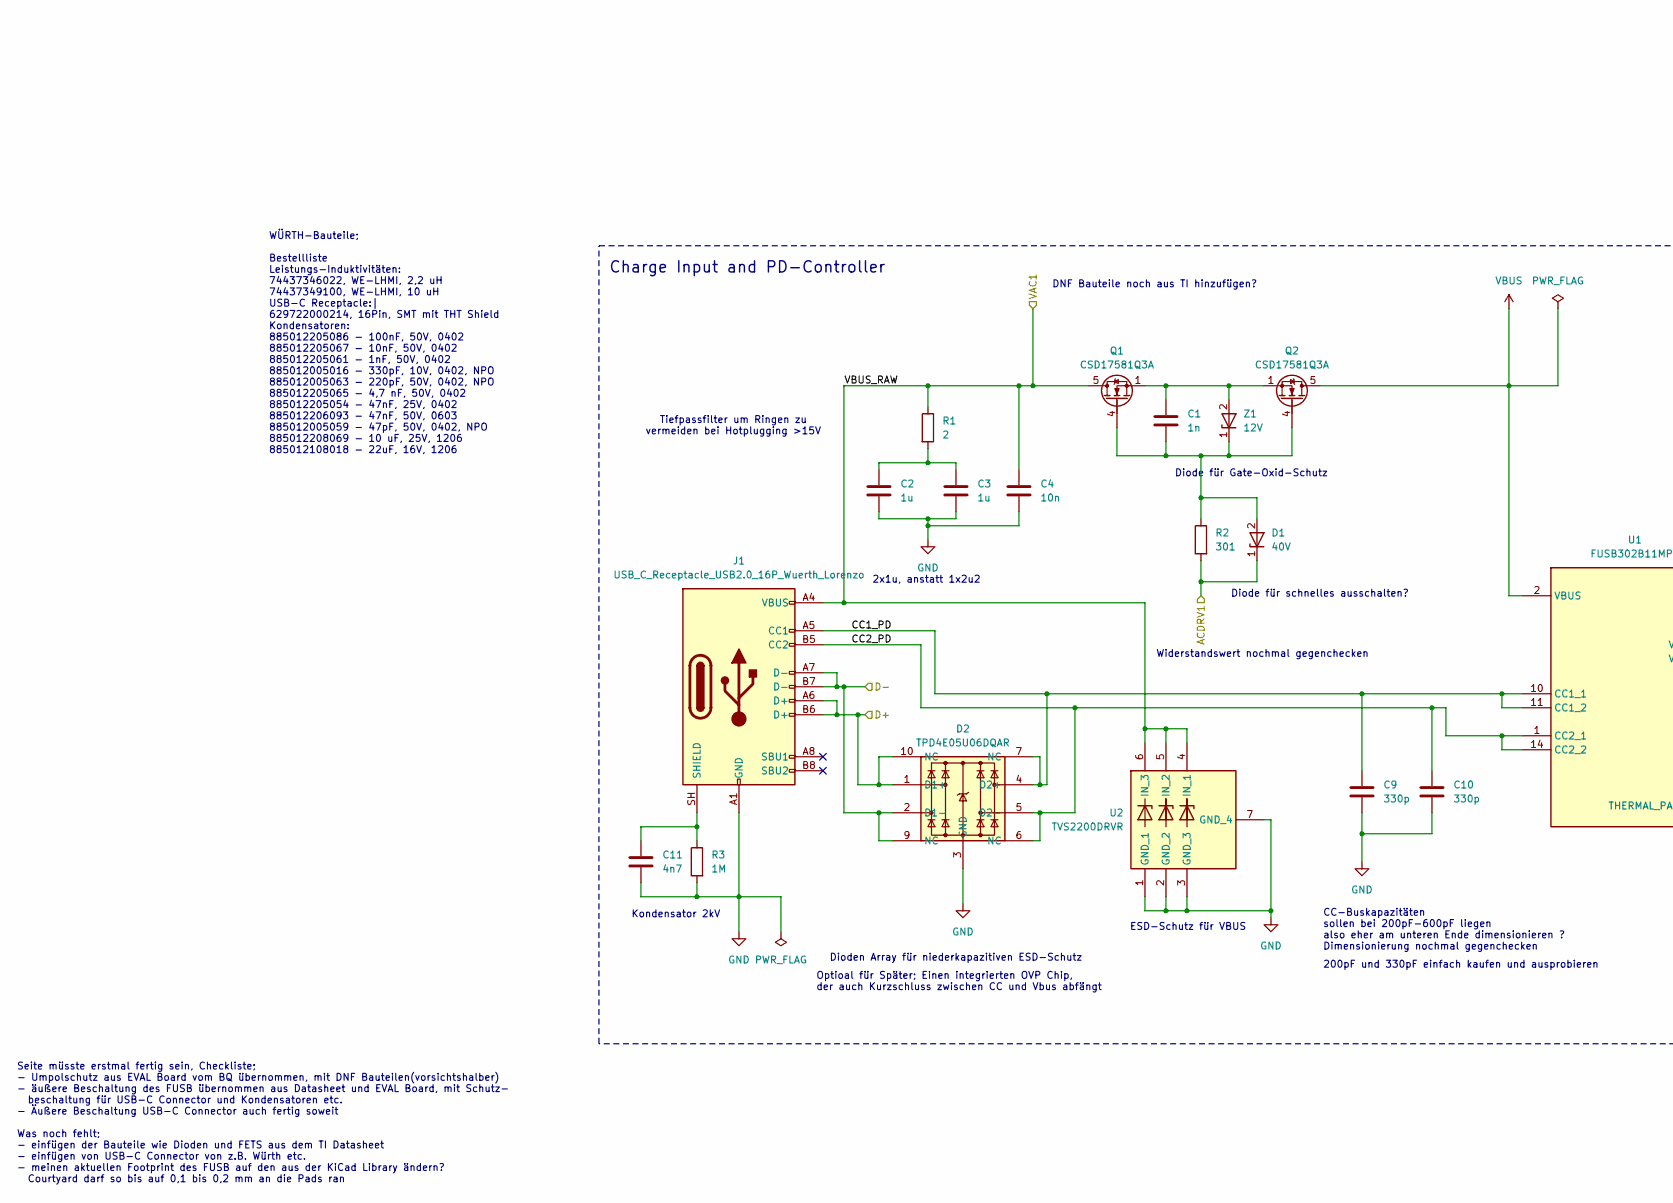
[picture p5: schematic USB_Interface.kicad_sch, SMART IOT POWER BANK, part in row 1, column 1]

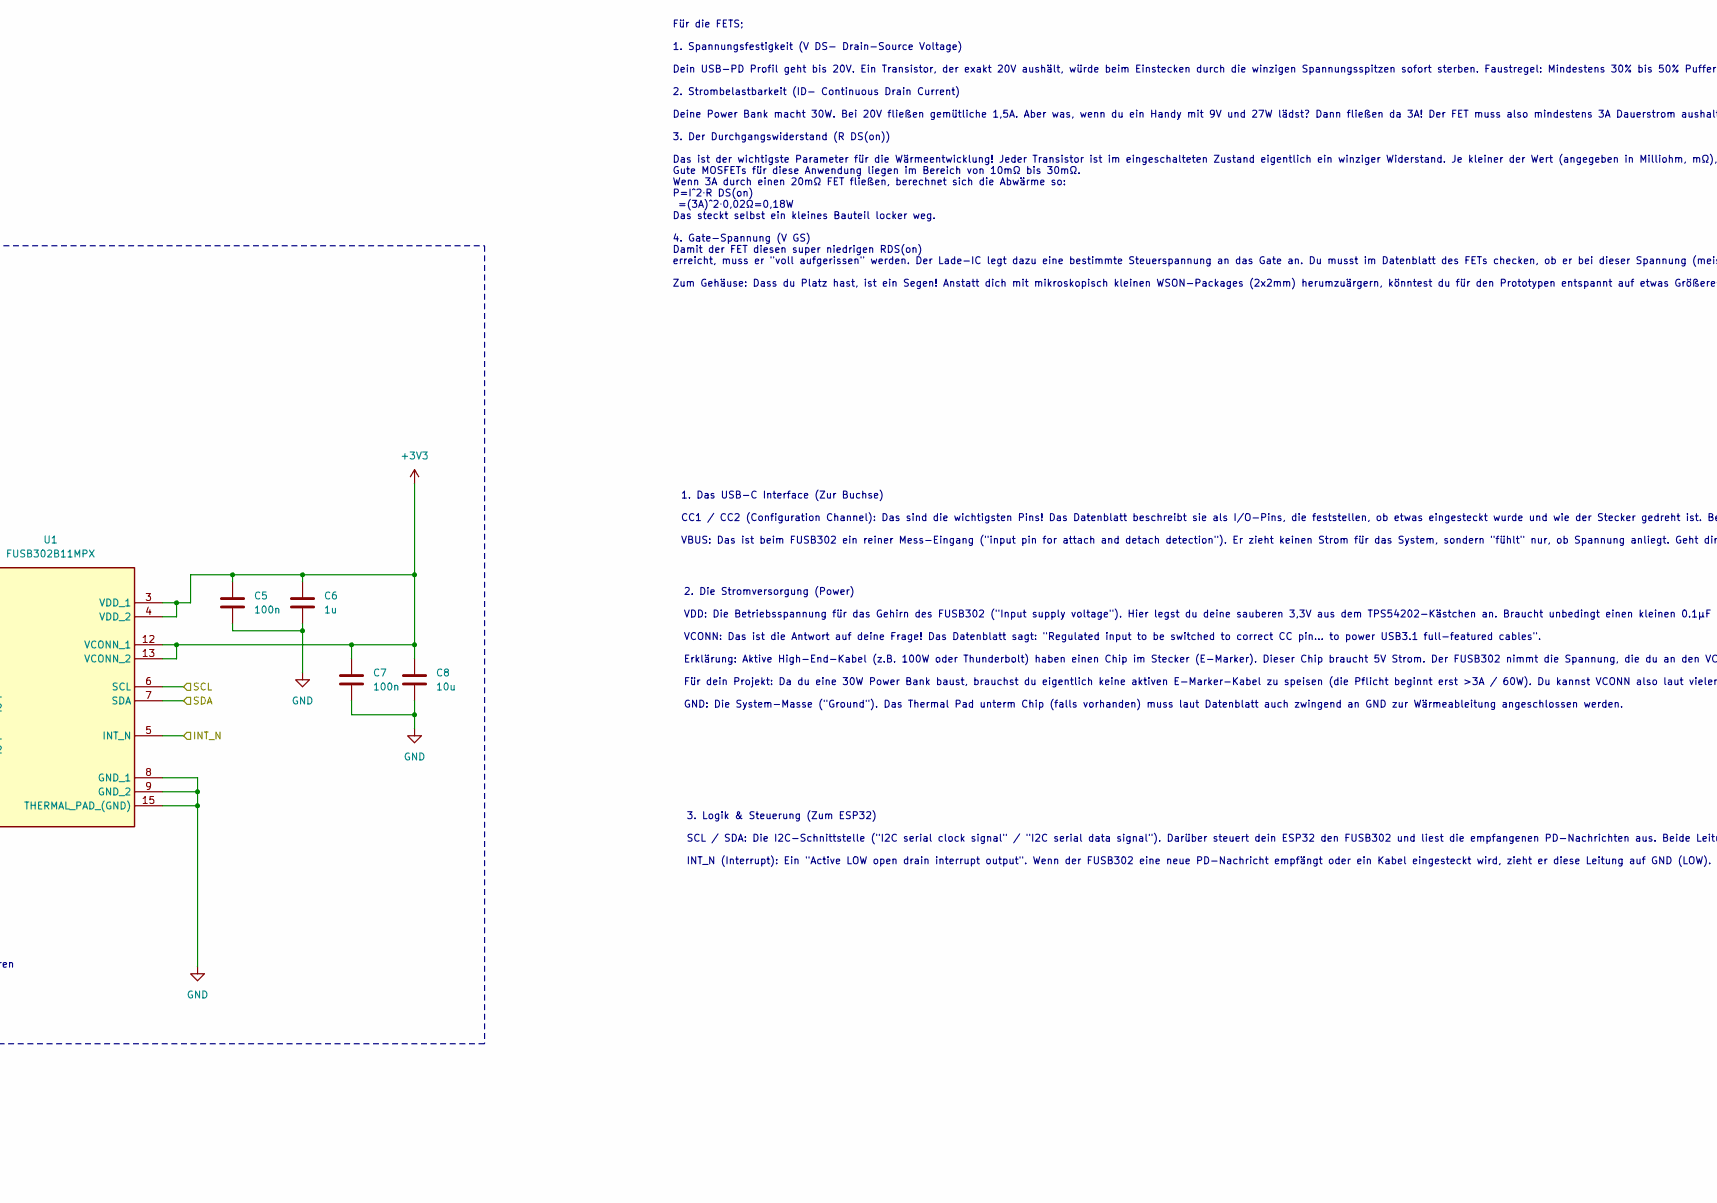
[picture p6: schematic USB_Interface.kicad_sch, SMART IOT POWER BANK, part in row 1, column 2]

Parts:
C1: 1n; C_Wurth_WCAP-CSGP-0402; Voltage 50.0; Part Number 885012205061
C2, C3, C6: 1u; C_Wurth_WCAP-CSGP-1206_H1.6; Voltage 50.0; Part Number 885012208093
C4: 10n; C_Wurth_WCAP-CSGP-0402; Voltage 50.0; Part Number 885012205067
C5, C7: 100n; C_Wurth_WCAP-CSGP-0402; Voltage 50.0; Part Number 885012205086
C8: 10u; C_Wurth_WCAP-CSGP-1206_H1.6; Voltage 25.0; Part Number 885012208069
C9, C10: 330p; C_Wurth_WCAP-CSGP-0402; Voltage 10.0; Part Number 885012005016
C11: 4n7; C_Wurth_WCAP-CSGP-0402; Voltage 50.0; Part Number 885012205065
D1: 40V; SODFL1608X65N; Mouser Part Number 522-ZLLS350TA
D2: TPD4E05U06DQAR; DQA_R-PUSON-N10_; Mouser Part Number 595-TPD4E05U06DQAR
J1: USB_C_Receptacle_USB2.0_16P_Wuerth_Lorenzo; 629722000214; Manufacturer_Part_Number 629722000214
Q1, Q2: CSD17581Q3A; CSD17581Q3A_LorenzonF; Manufacturer_Part_Number CSD17581Q3A
R1: 2; R_Wurth_WRIS-RSKS-0402; Part Number 560112110057
R2: 301; R_Wurth_WRIS-RSKS-0402; Part Number 560112110092
R3: 1M; R_Wurth_WRIS-RSKS-0402; Part Number 560112110033
U1: FUSB302B11MPX; QFN50P250X250X80-15N; Mouser Part Number 512-FUSB302B11MPX
U2: TVS2200DRVR; SON65P200X200X80-7N; Mouser Part Number 595-TVS2200DRVR
Z1: 12V; SOD3716X145N; Mouser Part Number 621-MMSZ5242B-F

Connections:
+3V3: C5.1, C6.1, C7.1, C8.1, U1.3 (VDD_1), U1.4 (VDD_2), U1.12 (VCONN_1), U1.13 (VCONN_2); also elsewhere on the board
/Charge_Controller/ACDRV1: D1.1 (K), R2.1; also elsewhere on the board
/Charge_Controller/D+: D2.1 (D1+), D2.10 (NC), J1.A6 (D+), J1.B6 (D+); also elsewhere on the board
/Charge_Controller/D-: D2.2 (D1-), D2.9 (NC), J1.A7 (D-), J1.B7 (D-); also elsewhere on the board
/MCU&Supply/I2C_SCL: U1.6 (SCL); also elsewhere on the board
/MCU&Supply/I2C_SDA: U1.7 (SDA); also elsewhere on the board
/MCU&Supply/INT_FUSB: U1.5 (INT_N); also elsewhere on the board
/USB_Interface/CC1_PD: C9.1, D2.4 (D2+), D2.7 (NC), J1.A5 (CC1), U1.10 (CC1_1), U1.11 (CC1_2)
/USB_Interface/CC2_PD: C10.1, D2.5 (D2-), D2.6 (NC), J1.B5 (CC2), U1.1 (CC2_1), U1.14 (CC2_2)
/USB_Interface/VBUS_RAW: C4.1, J1.A4 (VBUS), Q1.5 (D), R1.2, U2.4 (IN_1), U2.5 (IN_2), U2.6 (IN_3); also elsewhere on the board
GND: C2.2, C3.2, C4.2, C5.2, C6.2, C7.2, C8.2, C9.2, C10.2, C11.2, D2.3 (GND), D2.8 (GND), J1.A1 (GND), R3.1, U1.8 (GND_1), U1.9 (GND_2), U1.15 (THERMAL_PAD_(GND)), U2.1 (GND_1), U2.2 (GND_2), U2.3 (GND_3), U2.7 (GND_4); also elsewhere on the board
unnamed: C2.1, C3.1, R1.1
unnamed: C1.2, D1.2 (A), Q1.4 (G), Q2.4 (G), R2.2, Z1.1 (K)
unnamed: C11.1, J1.SH (SHIELD), R3.2
unnamed: C1.1, Q1.1 (S), Q1.2 (S), Q1.3 (S), Q2.1 (S), Q2.2 (S), Q2.3 (S), Z1.2 (A)
VBUS: Q2.5 (D), U1.2 (VBUS); also elsewhere on the board

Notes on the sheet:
1. Das USB-C Interface (Zur Buchse) CC1 / CC2 (Configuration Channel): Das sind die wichtigsten Pins! Das Datenblatt beschreibt sie als I/O-Pins, die feststellen, ob etwas eingesteckt wurde und wie der Stecker gedreht ist. Bei PD-Kommunikation senden und empfangen sie die eigentlichen Datenpakete (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
2. Die Stromversorgung (Power) VDD: Die Betriebsspannung für das Gehirn des FUSB302 ("Input supply voltage"). Hier legst du deine sauberen 3,3V aus dem TPS54202-Kästchen an. Braucht unbedingt einen kleinen 0.1µF (100nF) Entkoppelkondensator direkt am Pin nach GND! VCONN: Das ist die Antwort auf dei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
ESD-Schutz für VBUS
2x1u, anstatt 1x2u2
CC-Buskapazitäten sollen bei 200pF-600pF liegen also eher am unteren Ende dimensionieren ? Dimensionierung nochmal gegenchecken
Kondensator 2kV
Seite müsste erstmal fertig sein, Checkliste; - Umpolschutz aus EVAL Board vom BQ übernommen, mit DNF Bauteilen(vorsichtshalber) - äußere Beschaltung des FUSB übernommen aus Datasheet und EVAL Board, mit Schutz- beschaltung für USB-C Connector und Kondensatoren etc. - Äußere Beschaltung USB-C Conne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
Widerstandswert nochmal gegenchecken
Dioden Array für niederkapazitiven ESD-Schutz
Tiefpassfilter um Ringen zu vermeiden bei Hotplugging >15V
Diode für schnelles ausschalten?
Optioal für Später; Einen integrierten OVP Chip, der auch Kurzschluss zwischen CC und Vbus abfängt
Für die FETS; 1. Spannungsfestigkeit (V DS- Drain-Source Voltage) Dein USB-PD Profil geht bis 20V. Ein Transistor, der exakt 20V aushält, würde beim Einstecken durch die winzigen Spannungsspitzen sofort sterben. Faustregel: Mindestens 30% bis 50% Puffer. Du suchst also nach einem FET mit mindestens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
3. Logik & Steuerung (Zum ESP32) SCL / SDA: Die I2C-Schnittstelle ("I2C serial clock signal" / "I2C serial data signal"). Darüber steuert dein ESP32 den FUSB302 und liest die empfangenen PD-Nachrichten aus. Beide Leitungen brauchen einen Pull-up-Widerstand (meist 4.7kΩ) gegen 3,3V. INT_N (Interrupt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
Diode für Gate-Oxid-Schutz
Charge Input and PD-Controller
200pF und 330pF einfach kaufen und ausprobieren
WÜRTH-Bauteile; Bestellliste Leistungs-Induktivitäten: 74437346022, WE-LHMI, 2,2 uH 74437349100, WE-LHMI, 10 uH USB-C Receptacle:| 629722000214, 16Pin, SMT mit THT Shield Kondensatoren: 885012205086 - 100nF, 50V, 0402 885012205067 - 10nF, 50V, 0402 885012205061 - 1nF, 50V, 0402 885012005016 - 330pF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
DNF Bauteile noch aus TI hinzufügen?

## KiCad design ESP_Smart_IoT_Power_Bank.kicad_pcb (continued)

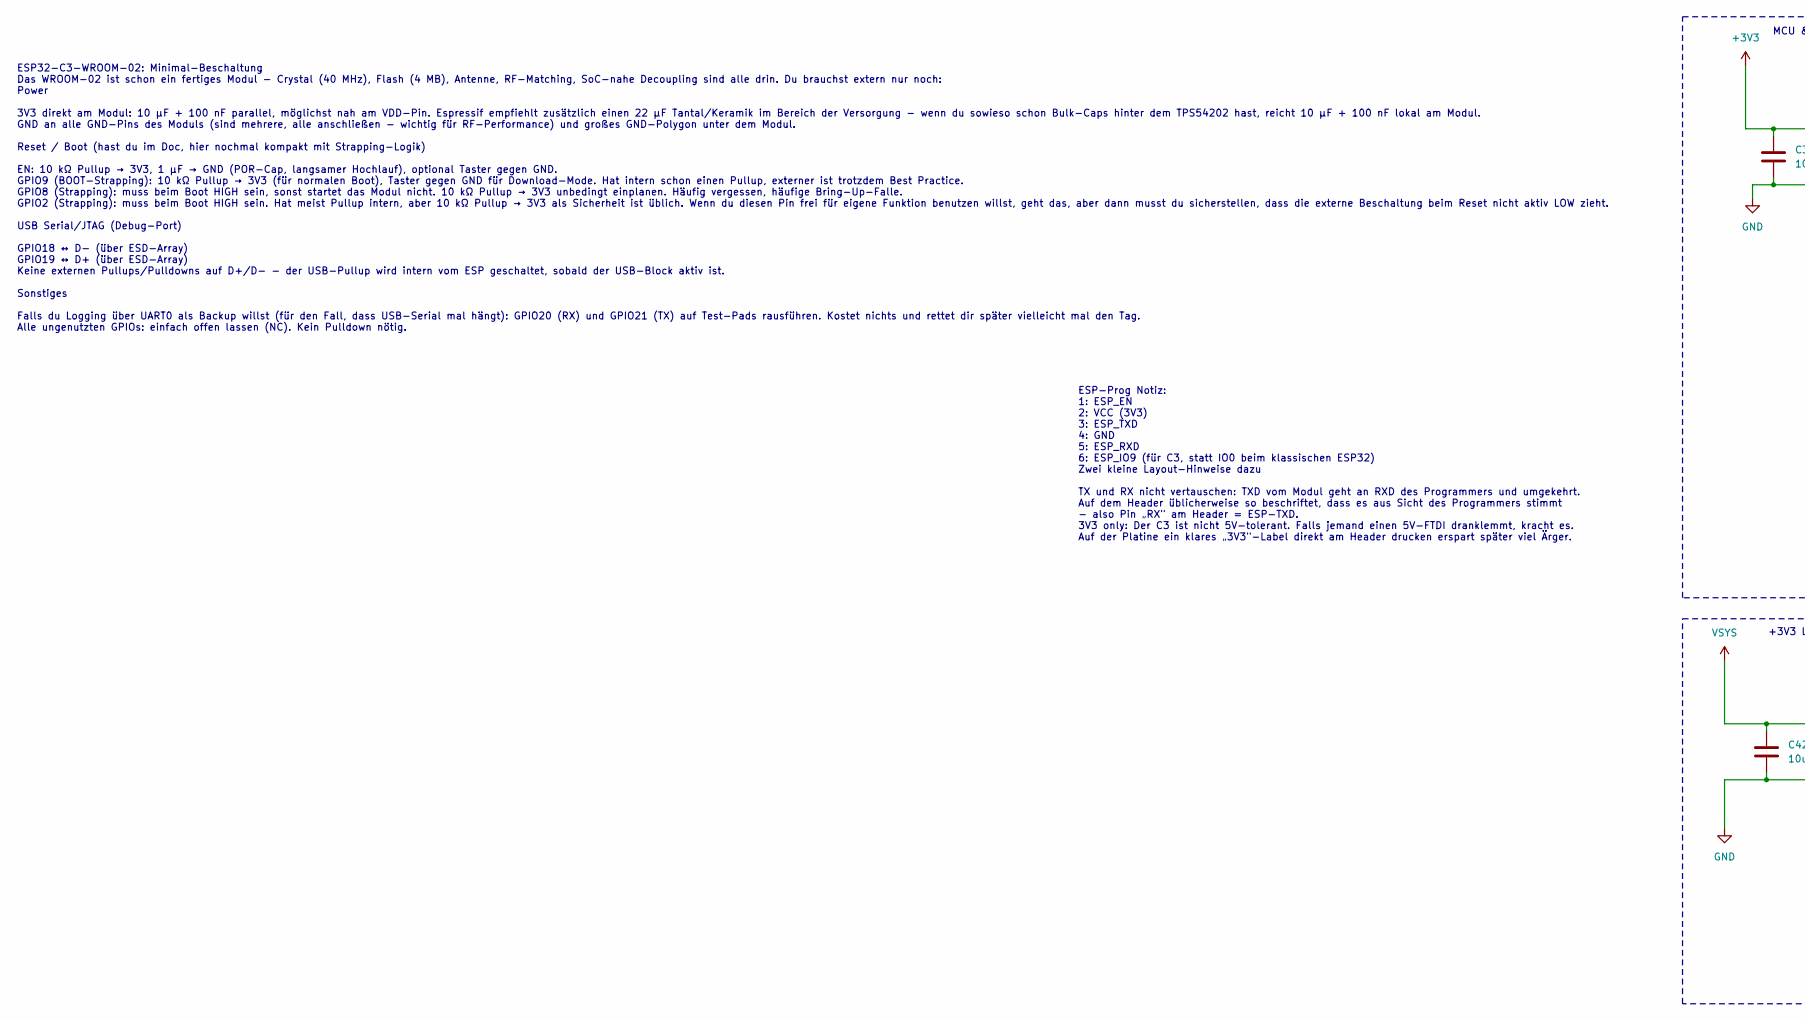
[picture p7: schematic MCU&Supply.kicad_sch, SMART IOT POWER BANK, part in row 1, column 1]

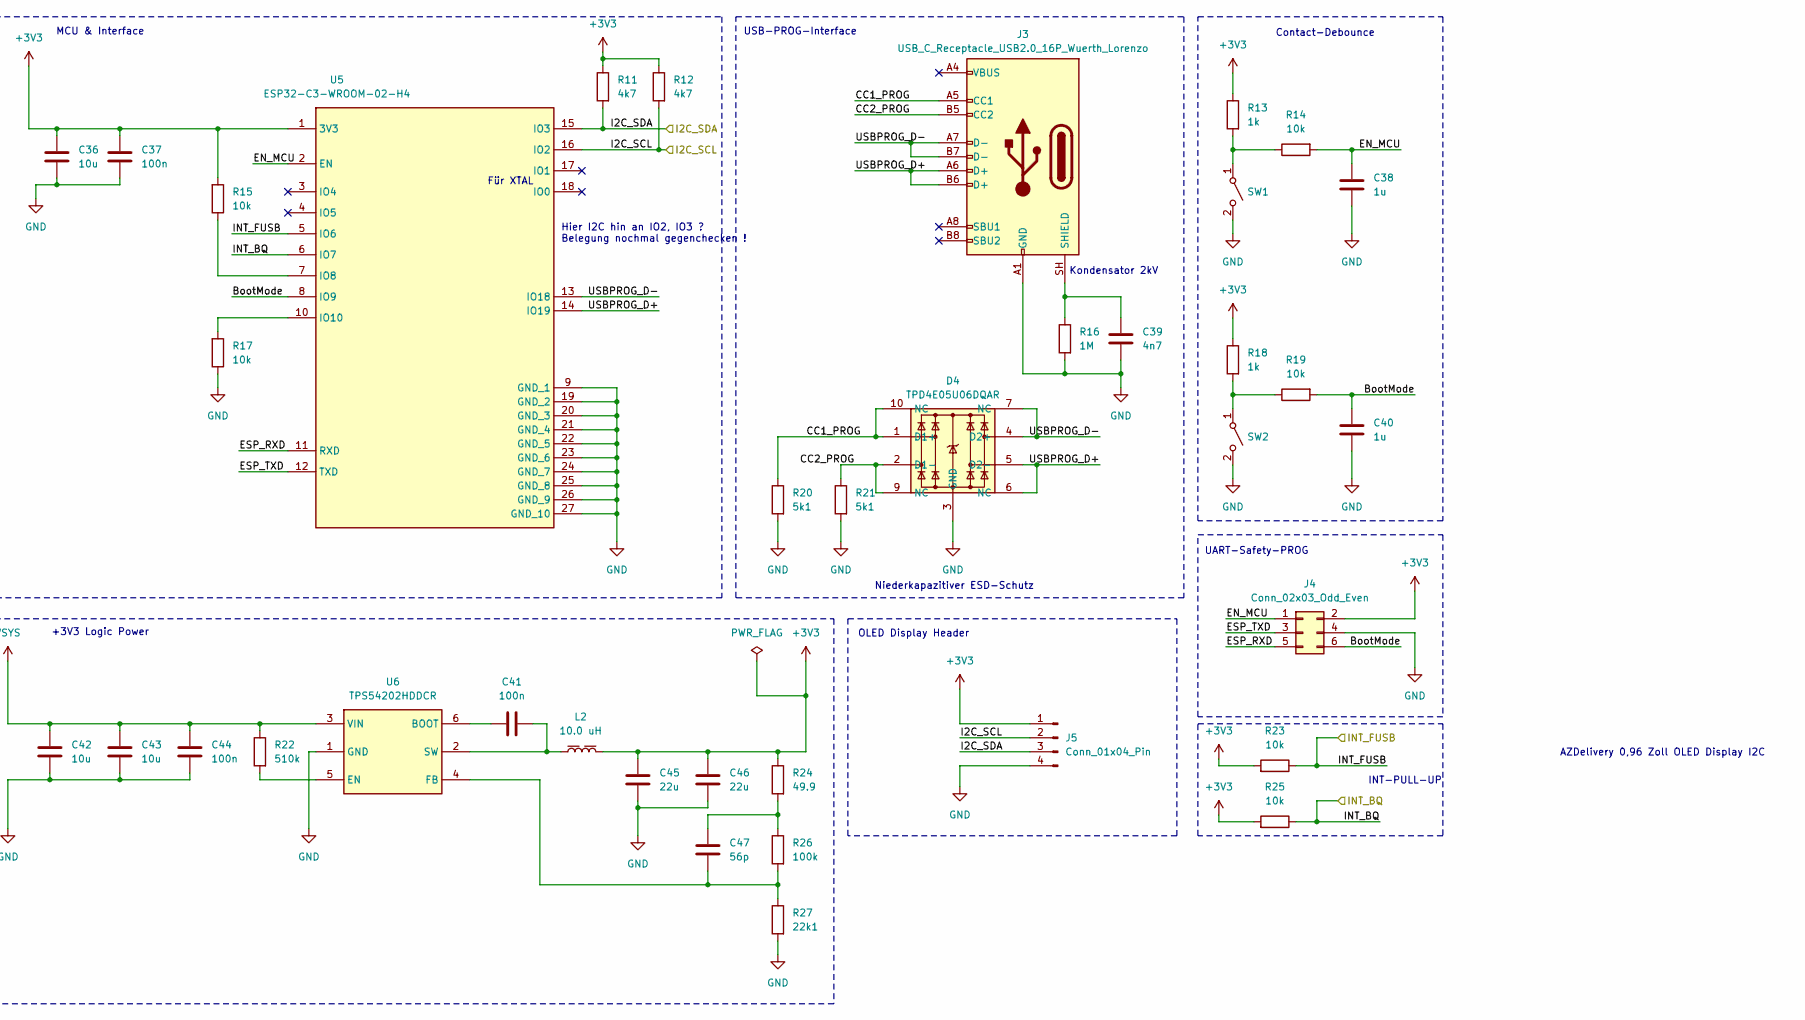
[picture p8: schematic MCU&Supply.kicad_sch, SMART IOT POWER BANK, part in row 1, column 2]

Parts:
C36, C42, C43: 10u; C_Wurth_WCAP-CSGP-1206_H1.6; Voltage 25.0; Part Number 885012208069
C37, C41, C44: 100n; C_Wurth_WCAP-CSGP-0402; Voltage 50.0; Part Number 885012205086
C38, C40: 1u; C_Wurth_WCAP-CSGP-1206_H1.6; Voltage 50.0; Part Number 885012208093
C39: 4n7; C_Wurth_WCAP-CSGP-0402; Voltage 50.0; Part Number 885012205065
C45, C46: 22u; C_Wurth_WCAP-CSGP-1206_H1.6; Voltage 16.0; Part Number 885012108018
C47: 56p; C_Wurth_WCAP-CSGP-0402; Mouser Part Number 77-VJ0402A560JXAAC
D4: TPD4E05U06DQAR; DQA_R-PUSON-N10_; Mouser Part Number 595-TPD4E05U06DQAR
J3: USB_C_Receptacle_USB2.0_16P_Wuerth_Lorenzo; 629722000214; Manufacturer_Part_Number 629722000214
J4: Conn_02x03_Odd_Even; PinHeader_2x03_P2.54mm_Vertical
J5: Conn_01x04_Pin; PinHeader_1x04_P2.54mm_Vertical
L2: 10.0 uH; L_Wurth_WE-LHMI-7050; Part Number 74437349100
R11, R12: 4k7; R_Wurth_WRIS-RSKS-0402; Part Number 560112110245
R13, R18: 1k; R_Wurth_WRIS-RSKS-0402; Part Number 560112110012
R14, R15, R17, R19, R23, R25: 10k; R_Wurth_WRIS-RSKS-0402; Part Number 560112110020
R16: 1M; R_Wurth_WRIS-RSKS-0402; Part Number 560112110033
R20, R21: 5k1; R_Wurth_WRIS-RSKS-0402; Manufacturer_Part_Number ERJ2RKF5101X
R22: 510k; R_Wurth_WRIS-RSKS-0402; Manufacturer_Part_Number ERJ-U02F5103X
R24: 49.9; R_Wurth_WRIS-RSKS-0402; Part Number 560112110002
R26: 100k; R_Wurth_WRIS-RSKS-0402; Part Number 560112110019
R27: 22k1; R_Wurth_WRIS-RSKS-0402; Part Number 560112110099
SW1, SW2: 434121025816; SW_Wurth_WS-TASV_434121025816; Part Number 434121025816
U5: ESP32-C3-WROOM-02-H4; ESP32C3WROOM02H4; Mouser Part Number 356-ESP32C3WROOM02H4
U6: TPS54202HDDCR; SOT95P280X110-6N; Mouser Part Number 595-TPS54202HDDCR

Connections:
+3V3: C36.1, C37.1, C45.2, C46.2, J4.2, J5.1, L2.2, R11.2, R12.2, R13.2, R15.1, R18.2, R23.1, R24.2, R25.1, U5.1 (3V3); also elsewhere on the board
/Charge_Controller/~INT: R25.2, U5.6 (IO7); also elsewhere on the board
/MCU&Supply/BootMode: C40.1, J4.6, R19.1, U5.8 (IO9)
/MCU&Supply/CC1_PROG: D4.1 (D1+), D4.10 (NC), J3.A5 (CC1), R20.2
/MCU&Supply/CC2_PROG: D4.2 (D1-), D4.9 (NC), J3.B5 (CC2), R21.2
/MCU&Supply/EN_MCU: C38.1, J4.1, R14.1, U5.2 (EN)
/MCU&Supply/ESP_RXD: J4.5, U5.11 (RXD)
/MCU&Supply/ESP_TXD: J4.3, U5.12 (TXD)
/MCU&Supply/I2C_SCL: J5.2, R12.1, U5.16 (IO2); also elsewhere on the board
/MCU&Supply/I2C_SDA: J5.3, R11.1, U5.15 (IO3); also elsewhere on the board
/MCU&Supply/INT_FUSB: R23.2, U5.5 (IO6); also elsewhere on the board
/MCU&Supply/USBPROG_D+: D4.5 (D2-), D4.6 (NC), J3.A6 (D+), J3.B6 (D+), U5.14 (IO19)
/MCU&Supply/USBPROG_D-: D4.4 (D2+), D4.7 (NC), J3.A7 (D-), J3.B7 (D-), U5.13 (IO18)
GND: C36.2, C37.2, C38.2, C39.2, C40.2, C42.2, C43.2, C44.2, C45.1, C46.1, D4.3 (GND), D4.8 (GND), J3.A1 (GND), J4.4, J5.4, R16.1, R17.2, R20.1, R21.1, R27.1, SW1.2 (B), SW2.2 (B), U5.9 (GND_1), U5.19 (GND_2), U5.20 (GND_3), U5.21 (GND_4), U5.22 (GND_5), U5.23 (GND_6), U5.24 (GND_7), U5.25 (GND_8), U5.26 (GND_9), U5.27 (GND_10), U6.1 (GND); also elsewhere on the board
unnamed: C47.1, R24.1, R26.2
unnamed: C39.1, J3.SH (SHIELD), R16.2
unnamed: R13.1, R14.2, SW1.1 (A)
unnamed: R18.1, R19.2, SW2.1 (A)
unnamed: R15.2, U5.7 (IO8)
unnamed: R17.1, U5.10 (IO10)
unnamed: C41.1, U6.6 (BOOT)
unnamed: R22.1, U6.5 (EN)
unnamed: C47.2, R26.1, R27.2, U6.4 (FB)
unnamed: C41.2, L2.1, U6.2 (SW)
VSYS: C42.1, C43.1, C44.1, R22.2, U6.3 (VIN); also elsewhere on the board

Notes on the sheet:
Hier I2C hin an IO2, IO3 ? Belegung nochmal gegenchecken !
USB-PROG-Interface
UART-Safety-PROG
+3V3 Logic Power
Kondensator 2kV
OLED Display Header
MCU & Interface
AZDelivery 0,96 Zoll OLED Display I2C
ESP-Prog Notiz: 1: ESP_EN 2: VCC (3V3) 3: ESP_TXD 4: GND 5: ESP_RXD 6: ESP_IO9 (für C3, statt IO0 beim klassischen ESP32) Zwei kleine Layout-Hinweise dazu TX und RX nicht vertauschen: TXD vom Modul geht an RXD des Programmers und umgekehrt. Auf dem Header üblicherweise so beschriftet, dass es aus S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
INT-PULL-UP
ESP32-C3-WROOM-02: Minimal-Beschaltung Das WROOM-02 ist schon ein fertiges Modul - Crystal (40 MHz), Flash (4 MB), Antenne, RF-Matching, SoC-nahe Decoupling sind alle drin. Du brauchst extern nur noch: Power 3V3 direkt am Modul: 10 µF + 100 nF parallel, möglichst nah am VDD-Pin. Espressif empfiehlt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
Für XTAL
Niederkapazitiver ESD-Schutz
Contact-Debounce

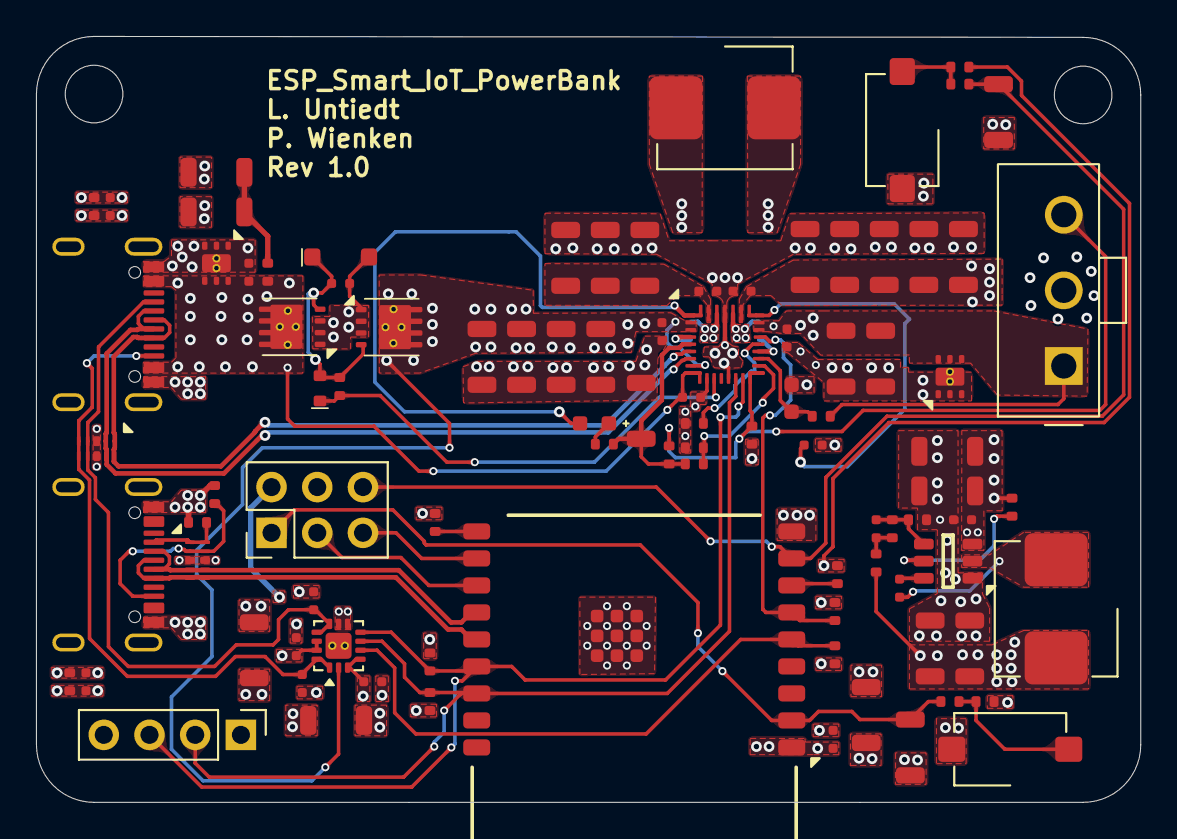
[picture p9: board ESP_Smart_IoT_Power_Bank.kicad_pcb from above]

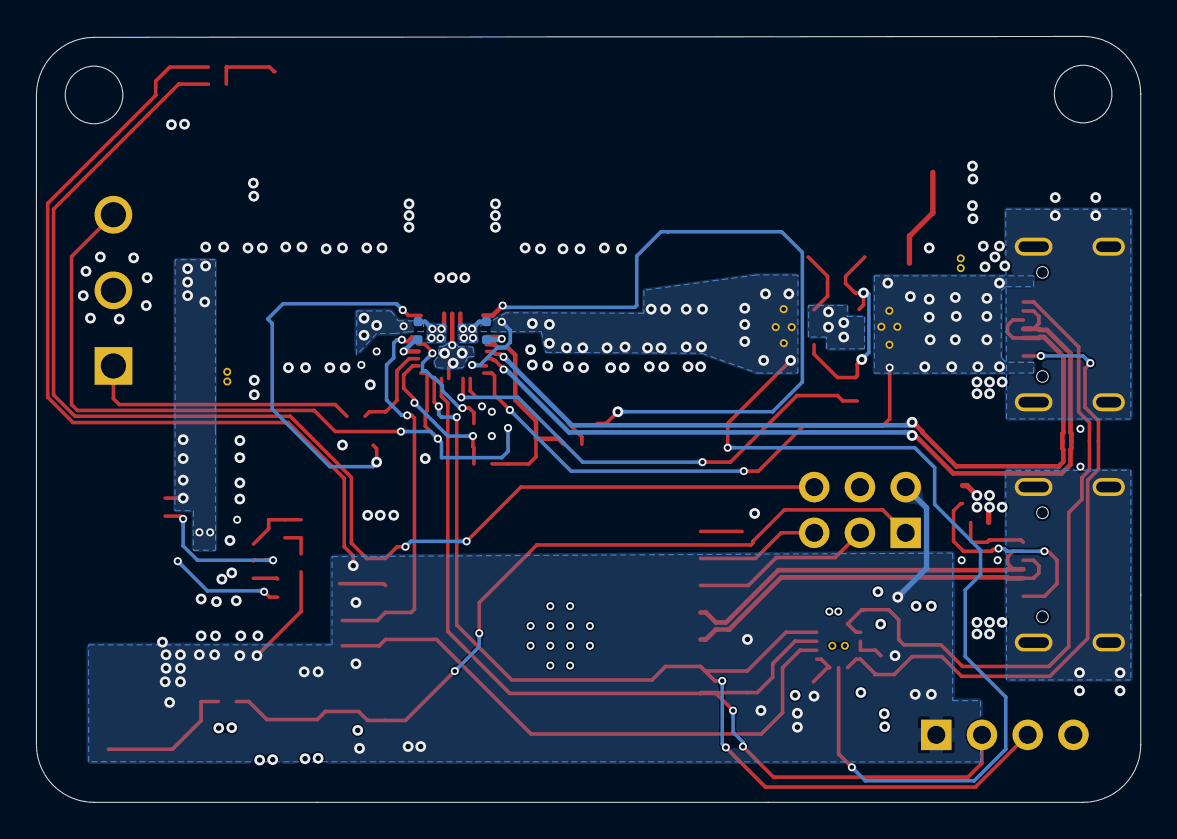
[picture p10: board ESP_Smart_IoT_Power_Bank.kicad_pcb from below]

Board: 4 copper layers, 61.4 x 42.5 mm, 98 parts (2 on the bottom side), 50 nets.

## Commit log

2026-06-07 Updated Files
    [Charge_Controller.kicad_sch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]
2026-06-21 Revise inductor values for U3 and U6 components
    Updated inductor specifications for U3 and U6 in the Power Path section.
2026-06-21 Revise thermal management section in README
    Updated thermal management guidelines to emphasize high power rails and via distribution.
